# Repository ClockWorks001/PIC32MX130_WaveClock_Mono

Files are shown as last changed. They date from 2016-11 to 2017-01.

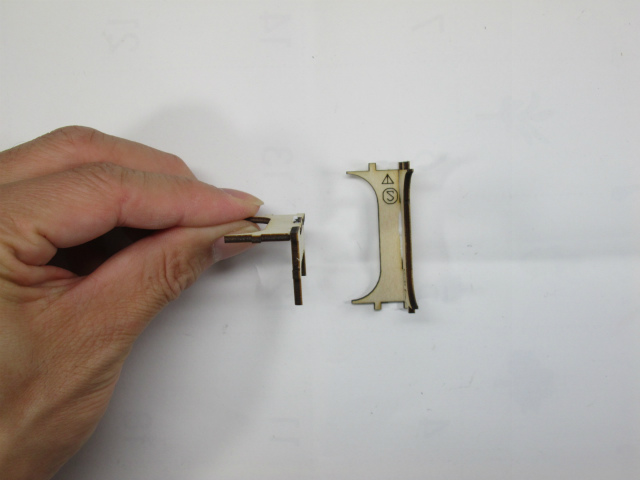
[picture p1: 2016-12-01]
組み立て参考情報【ケース】/IMG_1208.JPG

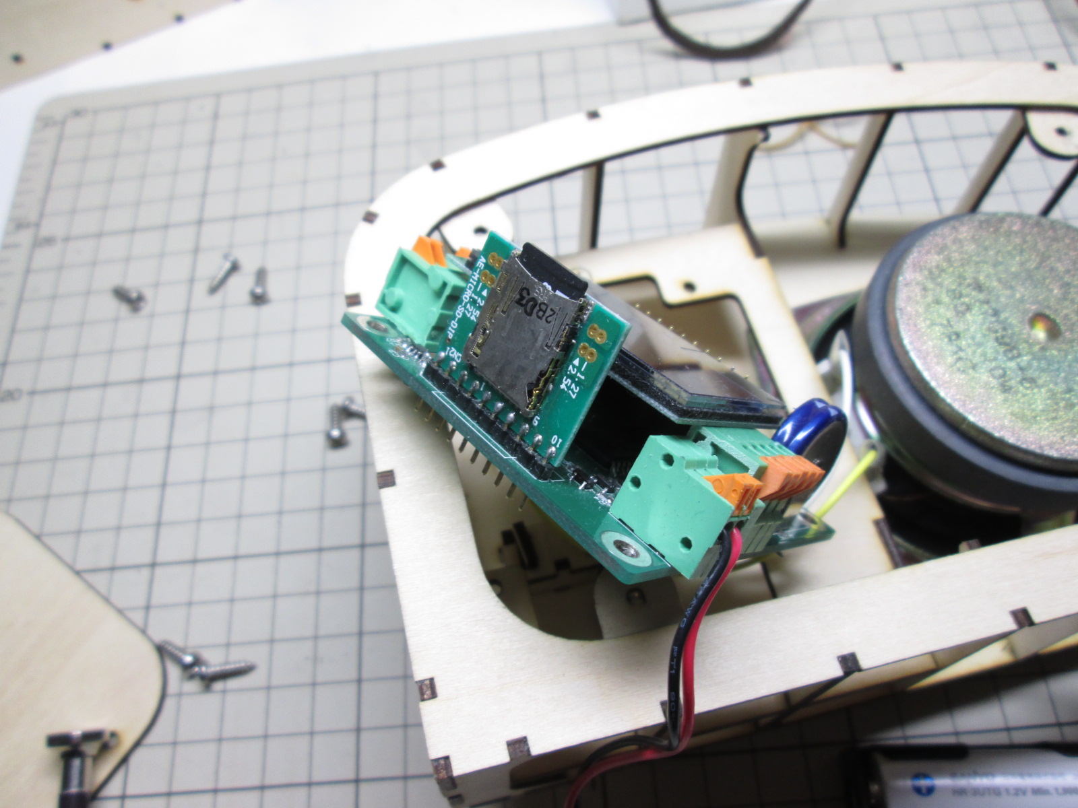
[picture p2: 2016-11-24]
組み立て参考情報/SDカードコネクタの取り付け位置①.JPG

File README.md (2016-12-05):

# PIC32MX130F Speaking Clock Project.
---
This is a wave player  project with PIC32MX130 micro controller.
It can speak a "time" by using wave files which are stored in a SD card. 
And it also can play music wave files.

## Description

References.
  <http://microchip.wikidot.com/>

## Prerequisites

I created this project using the free versions of the following tools:
 * [Microchip MPLAB X][2] (v3.35)
 * [Microchip XC32 Compiler][3] (v1.3)
 * [EAGLE][6] (v4.0.1)

You will need to download and install these tools appropriately before you
can open this project and build it.
I use the [Microchip MPLAB PICkit3 In-Circuit Debugger][5] to program the chip and debug it.  

Also, I use the [EAGLE][6] to draw the electric circuit schematic.

## Licence

[MIT](https://github.com/tcnksm/tool/blob/master/LICENCE)

## Author

Hiroshi Murakami  
<https://github.com/ClockWorks001>  

[1]: http://ww1.microchip.com/downloads/en/DeviceDoc/60001168F.pdf "PIC32MXxxx"
[2]: http://www.microchip.com/pagehandler/en-us/family/mplabx/ "MPLAB X"
[3]: http://www.microchip.com/pagehandler/en_us/devtools/mplabxc/ "MPLAB XC Compilers"
[4]: http://www.microchip.com/harmony "MPLAB Harmony Configurator"
[5]: http://www.microchip.com/Developmenttools/ProductDetails.aspx?PartNO=PG164130 "MPLAB PICkit3 In-Circuit Debugger"
[6]: https://cadsoft.io/ "EAGLE"

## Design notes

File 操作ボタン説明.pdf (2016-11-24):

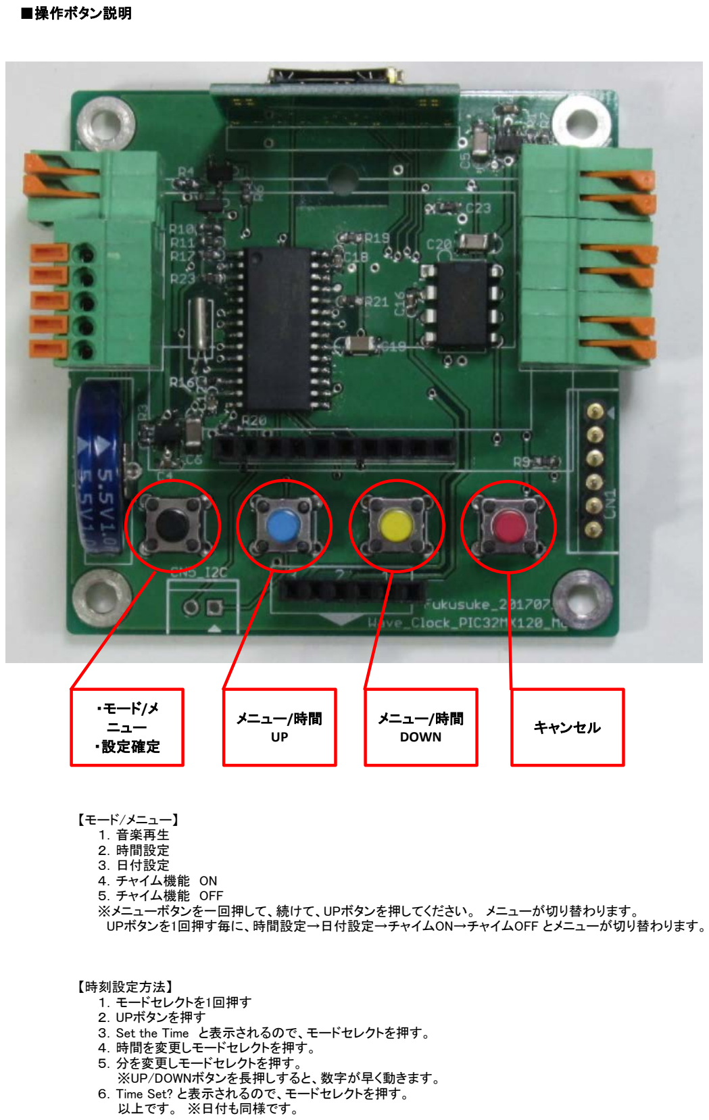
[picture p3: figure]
■操作ボタン説明; 【モード/メニュー】 １．音楽再生 ２．時間設定 ３．日付設定 ４．チャイム機能 ON ５．チャイム機能 OFF ※メニューボタンを一回押して、続けて、UPボタンを押してください。 メニューが切り替わります。 UPボタンを1回押す毎に、時間設定→日付設定→チャイムON→チャイムOFF とメニューが切り替わります。; 【時刻設定方法】 １．モードセレクトを1回押す ２．UPボタンを押す ３．Set the Time と表示されるので、モードセレクトを押す。 ４．時間を変更しモードセレクトを押す。 ５．分を変更しモードセレクトを押す。 ※UP/DOWNボタンを長押しすると、数字が早く動きます。 ６．Time Set? と表示されるので、モードセレクトを押す。 以上です。 ※日付も同様です。; ・モード/メ; ニュー ・設定確定; キャンセル メニュー/時間 UP; メニュー/時間 DOWN

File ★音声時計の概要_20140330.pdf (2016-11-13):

## 音声時計の概要_20140330.docx

音声時計の概要 2014.03.30

基本構成
1 CPU | PIC32MX130F064B
1.1 クロック | 40Mhz

## 1.2 ROM 64K 1.3 RAM 8K

2 周辺機能
2.1 microSD カード | 音声データ格納用
2.2 液晶表示器 | i2c_LCD SB1602B(ストロベリーリナックス)

## 2.3 オペアンプ（ローパスフィルタ） NJM8202 (JRC)

2.4 オーディオアンプ | HT82V739
2.5 入力スイッチ | 4 入力

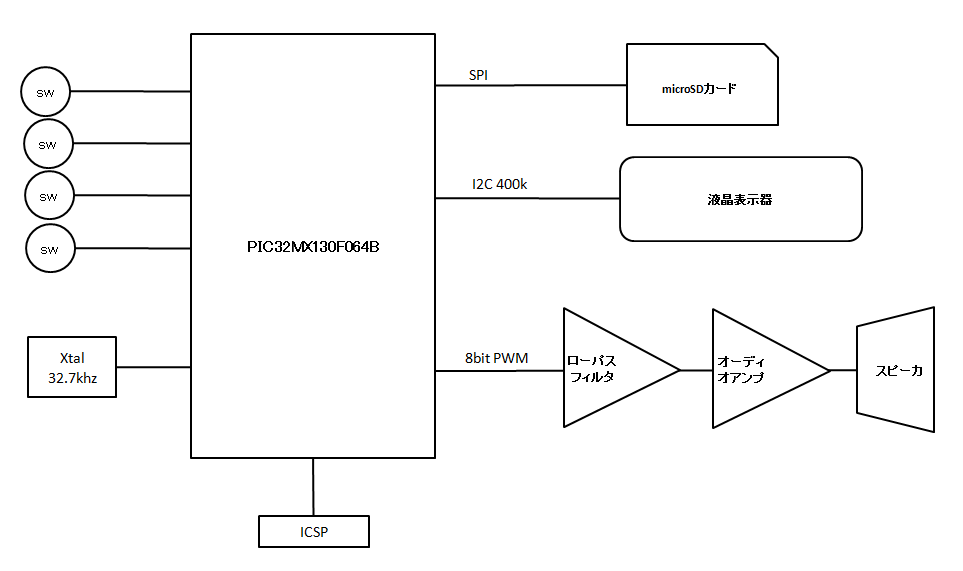
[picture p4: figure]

3 基本機能
3.1 ボタンを押すと、現在時刻を発話
3.2 時報機能。15 分ごとに現在時刻を発生。

## 3.3 PCM 音楽再生機能

3.4 音声データについては microSD カードに .wav(PCM)形式で格納して使用。 4 ソフトウェアの基本構成
4.1 ファイルシステムとして、ChaN 氏の PetitFAT を使用。
4.2 RTCC から読み出した時刻を元に Wave ファイルを再生する。
4.3 Wave ファイルの再生能力
4.3.1 入力ファイル | ：モノラル・ステレオ／ 8bit、16bit／ ～44.1Khz
4.3.2 出力 | ：モノラル／ 8bit PWM／ ～44.1Khz

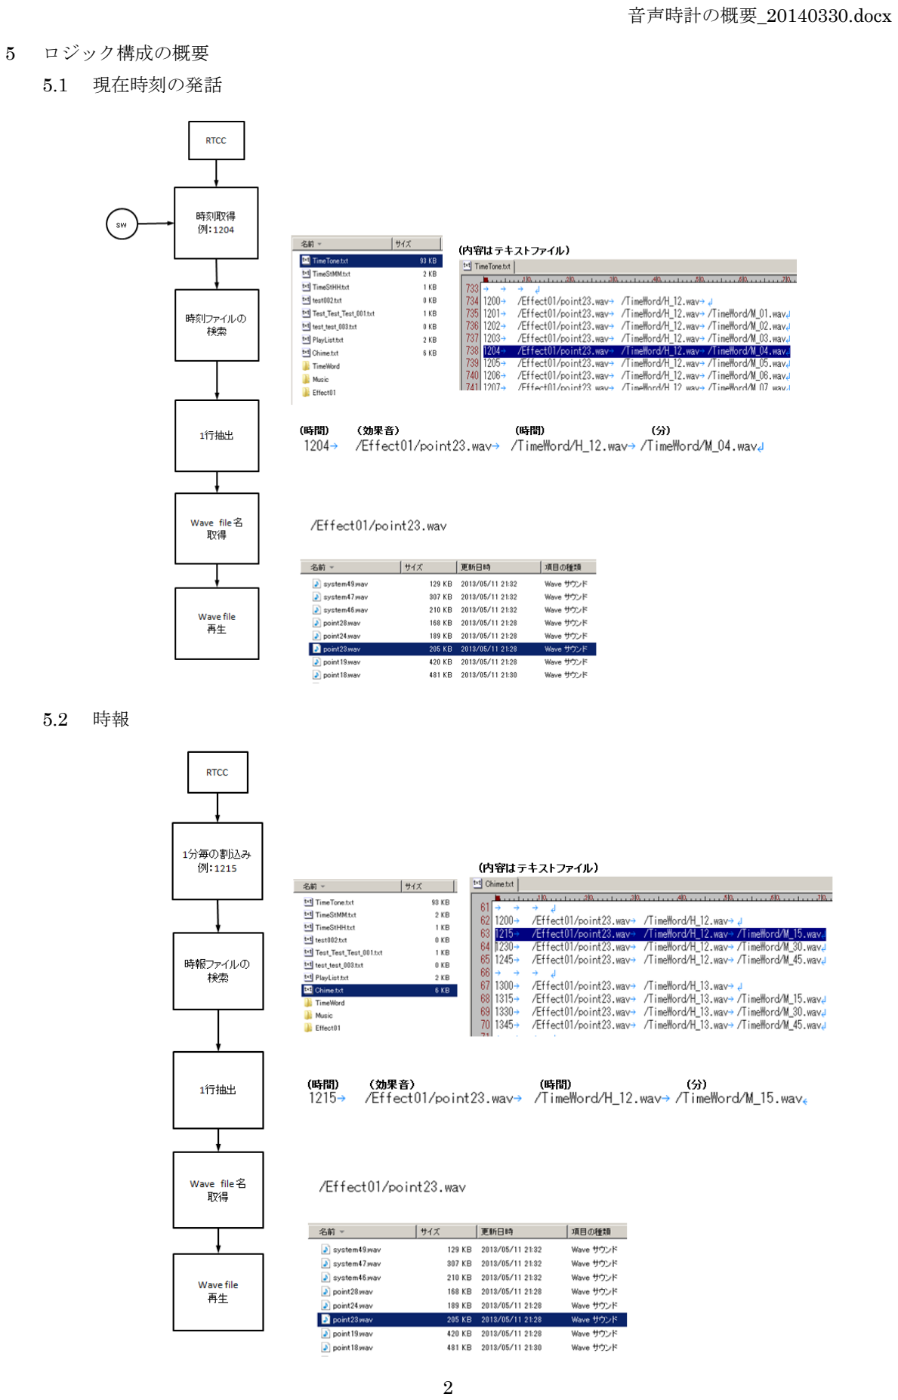
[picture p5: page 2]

5 ロジック構成の概要
5.1 現在時刻の発話

5.2 時報

6 使用ツールについて
6.1 ソフトウェア | ：MPLAB v1.90 ／ XC32 v1.21
6.2 回路図 | ：EGLE 6.4.0 light (P 板.COM に発注)
6.3 CAD | ：JW_CAD
6.4 3D_CAD | ：Autodesk123D Design (shapeways へ発注)
7 ケースの作成について (ケースについて、初めて 3D_CAD を使用して、3D 出力して作成しました) 7.1 JW_CAD を使用して、平面の設計図を作成する。
7.1.1 組み立てた基板をデジカメで写し、それを JW_CAD に貼り付けて設計の元とする。

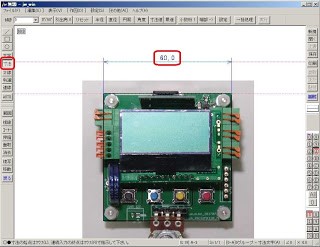
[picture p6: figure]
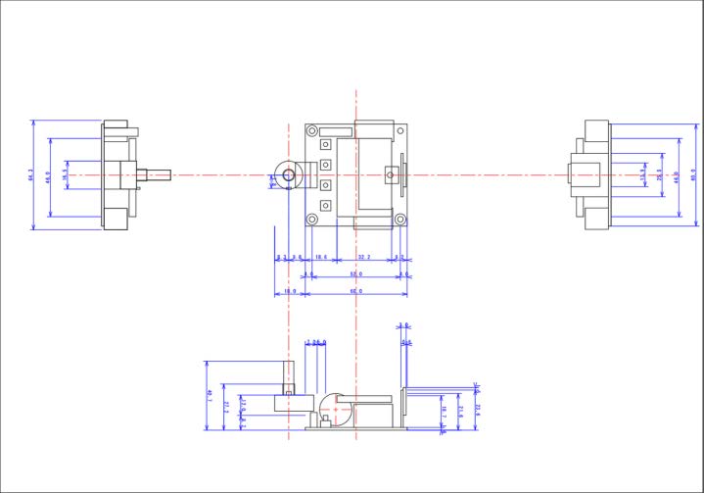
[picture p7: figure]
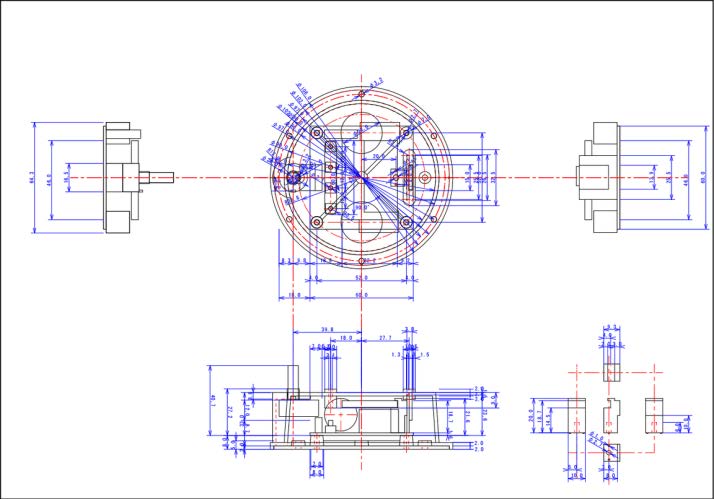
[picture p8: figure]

## 7.2 AutoCAD123 で 3D モデルを作成する。

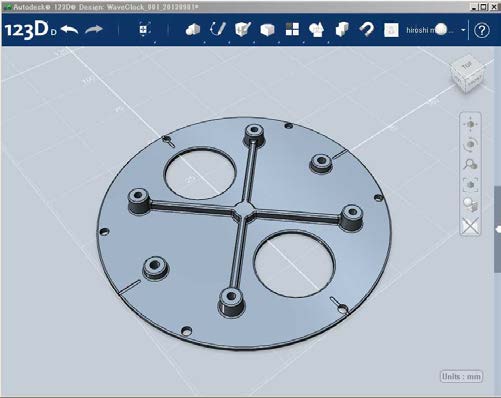
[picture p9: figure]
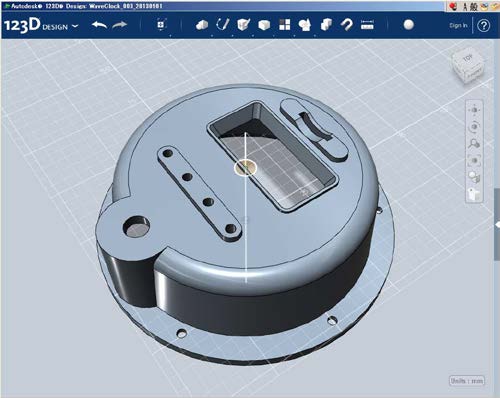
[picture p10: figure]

8 課題など
8.1 消費電力
8.1.1 オペアンプをレールツーレールのものを選択したが、無音時の待機電力が数ミリアンペアあ

り、削減が課題。
8.1.2 夜間に時報を発声してしまうので、センサを付けて明るさを検出する予定。
8.2 ユーザインターフェース部分の使いやすさの向上。
8.3 ファイルシステムを FatFs へ変更する。
8.4 ファイルの検索ロジックを、整理して再利用しやすくする。 8.5 Wave 再生ロジックについて、整理して再利用しやすくする。

※その他、下記ブログに音声時計の記事を記載しました。MPLAB のプロジェクトや設計図なども置いてあ

りますので、もしよろしければご参照ください。

## http://clockworks01.blogspot.jp/

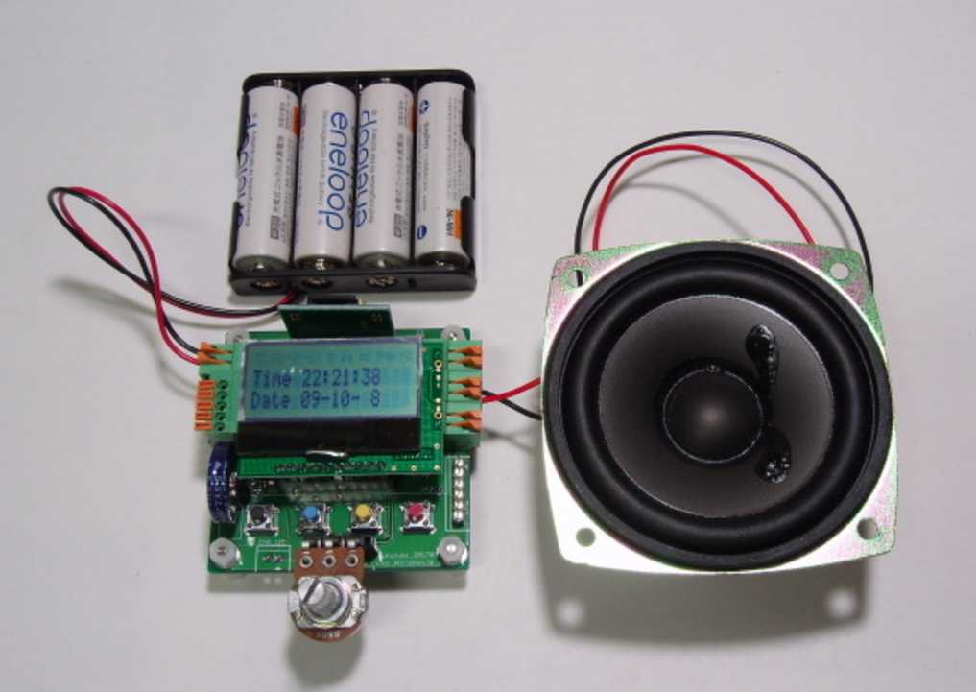
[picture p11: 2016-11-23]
組み立て参考情報/WS000727.JPG

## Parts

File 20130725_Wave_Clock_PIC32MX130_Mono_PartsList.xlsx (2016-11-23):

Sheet: 20130725_Wave_Clock_PIC32MX120_
Parts Listing
Part | Value | Package | 購入店
C7 | 1F | E5-19V-B | 秋月電子通商
C1 | 0.1uF | 1608 | 秋月電子通商
C2 | 0.1uF | 1608 | 秋月電子通商
C3 | 0.1uF | 1608 | 秋月電子通商
C4 | 0.1uF | 1608 | 秋月電子通商
C12 | 0.1uF | 1608 | 秋月電子通商
C17 | 0.1uF | 1608 | 秋月電子通商
C18 | 0.1uF | 1608 | 秋月電子通商
C21 | 0.1uF | 1608 | 秋月電子通商
C8 | 100pF | 1608 | 秋月電子通商
C11 | 100pF | 1608 | 秋月電子通商
C13 | 100pF | 1608 | 秋月電子通商
C14 | 100pF | 1608 | 秋月電子通商
C5 | 10uF | 3216 | 秋月電子通商
C6 | 10uF | 3216 | 秋月電子通商
C15 | 10uF | 3216 | 秋月電子通商
C19 | 10uF | 3216 | 秋月電子通商
C20 | 10uF | 3216 | 秋月電子通商
C22 | 10uF | 3216 | 秋月電子通商
C16 | 1uF | 1608 | 秋月電子通商
C23 | 1uF | 1608 | 秋月電子通商
C9 | 33pF | 1608 | 秋月電子通商
C10 | 33pF | 1608 | 秋月電子通商
BZ1 | R | TERMINAL_AH-2P | 秋月電子通商
CN2_POWER | CON_2P-B | TERMINAL_AH-2P | 秋月電子通商
CN6_SW | CON_2P-B | TERMINAL_AH-2P | 秋月電子通商
CN7_MOTOR | CON_2P-B | TERMINAL_AH-2P | 秋月電子通商
CN3_SWITCH | CON_5PVR | TERMINAL_AV-5P | 秋月電子通商
CN5_I2C | CON_2P-B | CON_DIP_2-B | 秋月電子通商
CN1 | CON_6P_ICSP-B | CON_DIP_6-B | 秋月電子通商
D1 | RB411D | SOT-23-3-2915-B | 秋月電子通商
IC1 | NJM2863F | SOT-23-5-2916-B | 秋月電子通商
IC2 | NJM2863F | SOT-23-5-2916-B | 秋月電子通商
IC3 | NJM8202R / LMV358QDGKR(12TI RHR) | MSOP08 | 秋月電子通商 / RSコンポーネンツ
IC4 | PIC32MX120F032B-I/SO | SO28W | digkey
IC5 | HT82V739 | DIP08-B | 秋月電子通商
IC6 | BD6211F | SOP8 | 秋月電子通商
LCD1 | LCD_I2CLCD_SB1602B | LCD_SB1602B | ストロベリーリナックス
R19 | 10 | 1608 | 秋月電子通商
R12 | 100 | 1608 | 秋月電子通商
R1 | 100K | 1608 | 秋月電子通商
R3 | 100K | 1608 | 秋月電子通商
R4 | 100K | 1608 | 秋月電子通商
R10 | 100K | 1608 | 秋月電子通商
R14 | 100K | 1608 | 秋月電子通商
R15 | 100K | 1608 | 秋月電子通商
R18 | 100K | 1608 | 秋月電子通商
R20 | 100K | 1608 | 秋月電子通商
R2 | 10K | 1608 | 秋月電子通商
R5 | 10K | 1608 | 秋月電子通商
R6 | 10K | 1608 | 秋月電子通商
R7 | 10K | 1608 | 秋月電子通商
R8 | 10K | 1608 | 秋月電子通商
R9 | 10K | 1608 | 秋月電子通商
R13 | 10K | 1608 | 秋月電子通商
R17 | 10K | 1608 | 秋月電子通商
R22 | 10K | 1608 | 秋月電子通商
R24 | 10K | 1608 | 秋月電子通商
R25 | 10K | 1608 | 秋月電子通商
R16 | 30K | 1608 | 秋月電子通商
R11 | 47K | 1608 | 秋月電子通商
R21 | 47K | 1608 | 秋月電子通商
R23 | 47K | 1608 | 秋月電子通商
SDC | DM3AT-SF-PEJ c | DM3AT-SF-DIP | 秋月電子通商
SW1 | SW_TACT1 | SW_TACT-B | 秋月電子通商
SW2 | SW_TACT1 | SW_TACT-B | 秋月電子通商
SW3 | SW_TACT1 | SW_TACT-B | 秋月電子通商
SW4 | SW_TACT1 | SW_TACT-B | 秋月電子通商
U1 | IRLML6402 | SC-59-2915 | 秋月電子通商
U2 | 2SC2712 | SOT-23-3-2915-B | 秋月電子通商
VR1 | ~~50K~~ 10K(A) | VOL_MIDDLE | 秋月電子通商
X1 | 32.768Khz | VT-200 | 秋月電子通商
 | 電池ボックス | 1
 | スピーカ | 1

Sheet: Sheet1
 | 0.1 uF | 100 pF | 10 uF
 | 1 uF | 33 pF
10 Ω |  | 100 Ω | 100 KΩ
10 KΩ |  | 30 KΩ | 47 KΩ

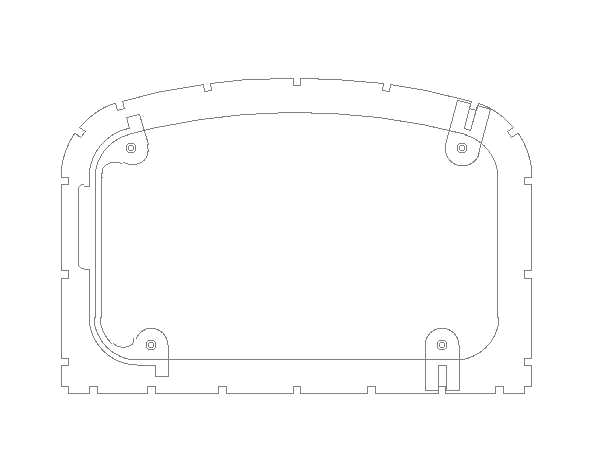
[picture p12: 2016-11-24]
組み立て参考情報【ケース】/IMG_1232_部品⑬は２種類.JPG

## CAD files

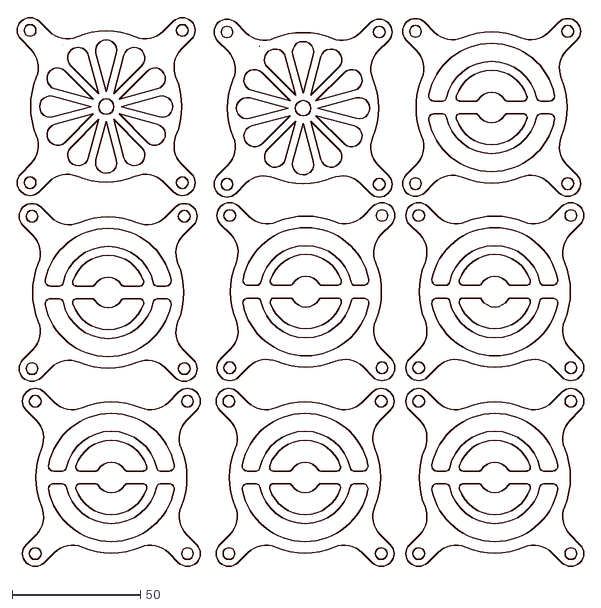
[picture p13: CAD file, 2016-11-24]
JWCAD/WaveClock_Mono_PIC32MX130_100.dxf
222.0 x 215.1

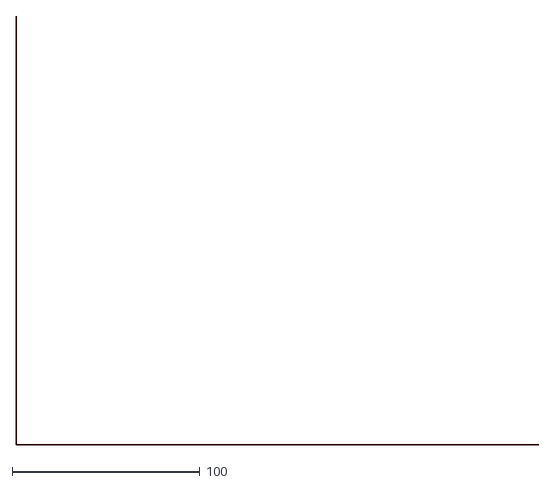
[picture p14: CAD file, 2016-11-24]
JWCAD/WaveClock_Mono_PIC32MX130_11_for_processing_00.dxf
278.0 x 228.0

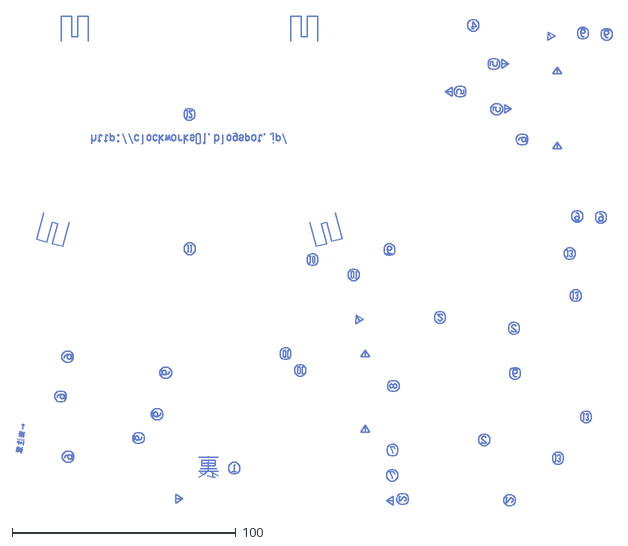
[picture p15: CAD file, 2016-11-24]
JWCAD/WaveClock_Mono_PIC32MX130_11_for_processing_01.dxf
266.3 x 218.6

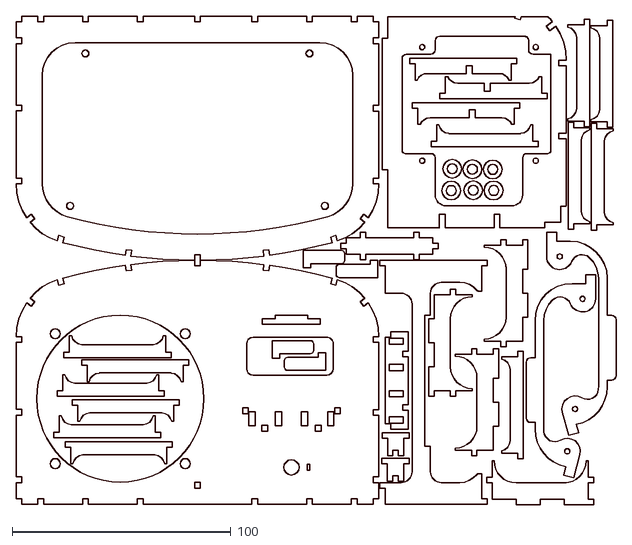
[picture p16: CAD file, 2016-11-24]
JWCAD/WaveClock_Mono_PIC32MX130_11_for_processing_02.dxf
274.4 x 223.4

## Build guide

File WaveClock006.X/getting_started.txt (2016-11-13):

This is a general template for the PIC32 family of microcontrollers.  It's
purpose is to provide a project shell for users to get started designing their
own applications.  Final qualification and testing of this project is left to
the user.

ADVANCED USER TIP

From the main menu, refer to the Task list by going to Window > Tasks (Ctrl+6).
As long as the task window is not configured to filter out any tasks,
the getting started TODO list embedded in this project will be displayed.

Make sure the 'Show tasks for the main project and for the open projects which
depend on it' option is selected on the left hand side of the Tasks window so
that tasks related to other projects are not active.

HOW TO ADD YOUR OWN CODE TO A TEMPLATE

STEP 1

First install the appropriate C compiler if you have not done so already.

See www.microchip.com/compilers

Next, build this project by clicking the Clean and Build Icon (the hammer and
broom symbol) in the MPLAB X IDE Toolbar.  If this project builds, then you are
ready to make changes for your own application.  If the project does not build,
you need to troubleshoot why the project does not build before moving on.

STEP 2

Embed your device's configuration bits into the code.  Instructions for this
are commented in configuration_bits.c

STEP 3

Unless interrupts are not used in your application, add the interrupt vectors
you intend to use to interrupts.c.  Code stubs are provided in interrupts.c.
Make sure that you check the device datasheet to confirm that the interrupt
you are using is present in the device selected, and check the device .h
file for the most up to date list of interrupt vector mnemonics.

STEP 4

Define system parameters such as the system operating frequency in system.h.

Add system level functions to system.h and system.c.  For example, if
you want a function to determine the reset source of the device to know if you
need to backup data, do an oscillator switch, enter a low power mode, etc...
these types of functions may be added to system.c and prototypes can go in
system.h.

STEP 5

Add user level functions to user.h and user.c.  User level functions are
functions that initialize I/O, initialize user peripherals like the ADC,
compute user algorithms, perform calculations on sampled user data, and so on.
User function prototypes and macros may be placed in user.h, and user
functions themselves may go in user.c

STEP 6

Add code to main.c on the line that says <INSERT USER APPLICATION CODE HERE>.
For example, here you would call functions in user.c or system.c, or possibly
setup your own state machine or primary code loop.

Global variables may be added to main.c as well.  As a general practice, macros
and prototypes may go in header files, but variable declarations should not
go in .h files.  Variable declarations should be placed in .c files.

STEP 7

Design the rest of your application.  Add new files to the application, and
test the finished product.

STEP 8

Document what the project does and include other project information in
project_information.txt.

KNOWN ISSUES

This message may appear after a successful build:

Configuration Bits: address 0x1FC02FF0: USERID = 22136 does not match any valid
value in the device database.  Setting it to the default value.

To avoid this message, the USERID may be embedded in the device as follows:

const int __attribute__((section(".config_BFC02FF0"))) configword_2ff0 = 0x12345678u;

(Adjust the address appropriately for the device in use if needed).

There will someday be a less painful way of embedding the USERID.  Until then,
this is how it can be done.

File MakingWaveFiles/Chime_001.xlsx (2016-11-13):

15分ごとの時間のお知らせ
 | 時間 | 分 | 格納先ディレクトリ |  | index
 | 00 | 00 | /TimeWord/ | na1_001.wav | 0000 | /Effect01/point23.wav | /TimeWord/H_00.wav
 | 00 | 15 | /TimeWord/ | point24.wav | 0015 | /Effect01/point23.wav | /TimeWord/H_00.wav | /TimeWord/M_15.wav
 | 00 | 30 | /TimeWord/ | point24.wav | 0030 | /Effect01/point23.wav | /TimeWord/H_00.wav | /TimeWord/M_30.wav
 | 00 | 45 | /TimeWord/ | point24.wav | 0045 | /Effect01/point23.wav | /TimeWord/H_00.wav | /TimeWord/M_45.wav
 | 01 | 00 | /TimeWord/ | na1_001.wav | 0100 | /Effect01/point23.wav | /TimeWord/H_01.wav
 | 01 | 15 | /TimeWord/ | point24.wav | 0115 | /Effect01/point23.wav | /TimeWord/H_01.wav | /TimeWord/M_15.wav
 | 01 | 30 | /TimeWord/ | point24.wav | 0130 | /Effect01/point23.wav | /TimeWord/H_01.wav | /TimeWord/M_30.wav
 | 01 | 45 | /TimeWord/ | point24.wav | 0145 | /Effect01/point23.wav | /TimeWord/H_01.wav | /TimeWord/M_45.wav
 | 02 | 00 | /TimeWord/ | na1_001.wav | 0200 | /Effect01/point23.wav | /TimeWord/H_02.wav
 | 02 | 15 | /TimeWord/ | point24.wav | 0215 | /Effect01/point23.wav | /TimeWord/H_02.wav | /TimeWord/M_15.wav
 | 02 | 30 | /TimeWord/ | point24.wav | 0230 | /Effect01/point23.wav | /TimeWord/H_02.wav | /TimeWord/M_30.wav
 | 02 | 45 | /TimeWord/ | point24.wav | 0245 | /Effect01/point23.wav | /TimeWord/H_02.wav | /TimeWord/M_45.wav
 | 03 | 00 | /TimeWord/ | na1_001.wav | 0300 | /Effect01/point23.wav | /TimeWord/H_03.wav
 | 03 | 15 | /TimeWord/ | point24.wav | 0315 | /Effect01/point23.wav | /TimeWord/H_03.wav | /TimeWord/M_15.wav
 | 03 | 30 | /TimeWord/ | point24.wav | 0330 | /Effect01/point23.wav | /TimeWord/H_03.wav | /TimeWord/M_30.wav
 | 03 | 45 | /TimeWord/ | point24.wav | 0345 | /Effect01/point23.wav | /TimeWord/H_03.wav | /TimeWord/M_45.wav
 | 04 | 00 | /TimeWord/ | na1_001.wav | 0400 | /Effect01/point23.wav | /TimeWord/H_04.wav
 | 04 | 15 | /TimeWord/ | point24.wav | 0415 | /Effect01/point23.wav | /TimeWord/H_04.wav | /TimeWord/M_15.wav
 | 04 | 30 | /TimeWord/ | point24.wav | 0430 | /Effect01/point23.wav | /TimeWord/H_04.wav | /TimeWord/M_30.wav
 | 04 | 45 | /TimeWord/ | point24.wav | 0445 | /Effect01/point23.wav | /TimeWord/H_04.wav | /TimeWord/M_45.wav
 | 05 | 00 | /TimeWord/ | na1_001.wav | 0500 | /Effect01/point23.wav | /TimeWord/H_05.wav
 | 05 | 15 | /TimeWord/ | point24.wav | 0515 | /Effect01/point23.wav | /TimeWord/H_05.wav | /TimeWord/M_15.wav
 | 05 | 30 | /TimeWord/ | point24.wav | 0530 | /Effect01/point23.wav | /TimeWord/H_05.wav | /TimeWord/M_30.wav
 | 05 | 45 | /TimeWord/ | point24.wav | 0545 | /Effect01/point23.wav | /TimeWord/H_05.wav | /TimeWord/M_45.wav
 | 06 | 00 | /TimeWord/ | na1_001.wav | 0600 | /Effect01/point23.wav | /TimeWord/H_06.wav
 | 06 | 15 | /TimeWord/ | point24.wav | 0615 | /Effect01/point23.wav | /TimeWord/H_06.wav | /TimeWord/M_15.wav
 | 06 | 30 | /TimeWord/ | point24.wav | 0630 | /Effect01/point23.wav | /TimeWord/H_06.wav | /TimeWord/M_30.wav
 | 06 | 45 | /TimeWord/ | point24.wav | 0645 | /Effect01/point23.wav | /TimeWord/H_06.wav | /TimeWord/M_45.wav
 | 07 | 00 | /TimeWord/ | na1_001.wav | 0700 | /Effect01/point23.wav | /TimeWord/H_07.wav
 | 07 | 15 | /TimeWord/ | point24.wav | 0715 | /Effect01/point23.wav | /TimeWord/H_07.wav | /TimeWord/M_15.wav
 | 07 | 30 | /TimeWord/ | point24.wav | 0730 | /Effect01/point23.wav | /TimeWord/H_07.wav | /TimeWord/M_30.wav
 | 07 | 45 | /TimeWord/ | point24.wav | 0745 | /Effect01/point23.wav | /TimeWord/H_07.wav | /TimeWord/M_45.wav
 | 08 | 00 | /TimeWord/ | na1_001.wav | 0800 | /Effect01/point23.wav | /TimeWord/H_08.wav
 | 08 | 15 | /TimeWord/ | point24.wav | 0815 | /Effect01/point23.wav | /TimeWord/H_08.wav | /TimeWord/M_15.wav
 | 08 | 30 | /TimeWord/ | point24.wav | 0830 | /Effect01/point23.wav | /TimeWord/H_08.wav | /TimeWord/M_30.wav
 | 08 | 45 | /TimeWord/ | point24.wav | 0845 | /Effect01/point23.wav | /TimeWord/H_08.wav | /TimeWord/M_45.wav
 | 09 | 00 | /TimeWord/ | na1_001.wav | 0900 | /Effect01/point23.wav | /TimeWord/H_09.wav
 | 09 | 15 | /TimeWord/ | point24.wav | 0915 | /Effect01/point23.wav | /TimeWord/H_09.wav | /TimeWord/M_15.wav
 | 09 | 30 | /TimeWord/ | point24.wav | 0930 | /Effect01/point23.wav | /TimeWord/H_09.wav | /TimeWord/M_30.wav
 | 09 | 45 | /TimeWord/ | point24.wav | 0945 | /Effect01/point23.wav | /TimeWord/H_09.wav | /TimeWord/M_45.wav
 | 10 | 00 | /TimeWord/ | na1_001.wav | 1000 | /Effect01/point23.wav | /TimeWord/H_10.wav
 | 10 | 15 | /TimeWord/ | point24.wav | 1015 | /Effect01/point23.wav | /TimeWord/H_10.wav | /TimeWord/M_15.wav
 | 10 | 30 | /TimeWord/ | point24.wav | 1030 | /Effect01/point23.wav | /TimeWord/H_10.wav | /TimeWord/M_30.wav
 | 10 | 45 | /TimeWord/ | point24.wav | 1045 | /Effect01/point23.wav | /TimeWord/H_10.wav | /TimeWord/M_45.wav
 | 11 | 00 | /TimeWord/ | na1_001.wav | 1100 | /Effect01/point23.wav | /TimeWord/H_11.wav
 | 11 | 15 | /TimeWord/ | point24.wav | 1115 | /Effect01/point23.wav | /TimeWord/H_11.wav | /TimeWord/M_15.wav
 | 11 | 30 | /TimeWord/ | point24.wav | 1130 | /Effect01/point23.wav | /TimeWord/H_11.wav | /TimeWord/M_30.wav
 | 11 | 45 | /TimeWord/ | point24.wav | 1145 | /Effect01/point23.wav | /TimeWord/H_11.wav | /TimeWord/M_45.wav
 | 12 | 00 | /TimeWord/ | na1_001.wav | 1200 | /Effect01/point23.wav | /TimeWord/H_12.wav
 | 12 | 15 | /TimeWord/ | point24.wav | 1215 | /Effect01/point23.wav | /TimeWord/H_12.wav | /TimeWord/M_15.wav
 | 12 | 30 | /TimeWord/ | point24.wav | 1230 | /Effect01/point23.wav | /TimeWord/H_12.wav | /TimeWord/M_30.wav
 | 12 | 45 | /TimeWord/ | point24.wav | 1245 | /Effect01/point23.wav | /TimeWord/H_12.wav | /TimeWord/M_45.wav
 | 13 | 00 | /TimeWord/ | na1_001.wav | 1300 | /Effect01/point23.wav | /TimeWord/H_13.wav
 | 13 | 15 | /TimeWord/ | point24.wav | 1315 | /Effect01/point23.wav | /TimeWord/H_13.wav | /TimeWord/M_15.wav
 | 13 | 30 | /TimeWord/ | point24.wav | 1330 | /Effect01/point23.wav | /TimeWord/H_13.wav | /TimeWord/M_30.wav
 | 13 | 45 | /TimeWord/ | point24.wav | 1345 | /Effect01/point23.wav | /TimeWord/H_13.wav | /TimeWord/M_45.wav
 | 14 | 00 | /TimeWord/ | na1_001.wav | 1400 | /Effect01/point23.wav | /TimeWord/H_14.wav
 | 14 | 15 | /TimeWord/ | point24.wav | 1415 | /Effect01/point23.wav | /TimeWord/H_14.wav | /TimeWord/M_15.wav
 | 14 | 30 | /TimeWord/ | point24.wav | 1430 | /Effect01/point23.wav | /TimeWord/H_14.wav | /TimeWord/M_30.wav
 | 14 | 45 | /TimeWord/ | point24.wav | 1445 | /Effect01/point23.wav | /TimeWord/H_14.wav | /TimeWord/M_45.wav
 | 15 | 00 | /TimeWord/ | na1_001.wav | 1500 | /Effect01/point23.wav | /TimeWord/H_15.wav
 | 15 | 15 | /TimeWord/ | point24.wav | 1515 | /Effect01/point23.wav | /TimeWord/H_15.wav | /TimeWord/M_15.wav
 | 15 | 30 | /TimeWord/ | point24.wav | 1530 | /Effect01/point23.wav | /TimeWord/H_15.wav | /TimeWord/M_30.wav
 | 15 | 45 | /TimeWord/ | point24.wav | 1545 | /Effect01/point23.wav | /TimeWord/H_15.wav | /TimeWord/M_45.wav
 | 16 | 00 | /TimeWord/ | na1_001.wav | 1600 | /Effect01/point23.wav | /TimeWord/H_16.wav
 | 16 | 15 | /TimeWord/ | point24.wav | 1615 | /Effect01/point23.wav | /TimeWord/H_16.wav | /TimeWord/M_15.wav
 | 16 | 30 | /TimeWord/ | point24.wav | 1630 | /Effect01/point23.wav | /TimeWord/H_16.wav | /TimeWord/M_30.wav
 | 16 | 45 | /TimeWord/ | point24.wav | 1645 | /Effect01/point23.wav | /TimeWord/H_16.wav | /TimeWord/M_45.wav
 | 17 | 00 | /TimeWord/ | na1_001.wav | 1700 | /Effect01/point23.wav | /TimeWord/H_17.wav
 | 17 | 15 | /TimeWord/ | point24.wav | 1715 | /Effect01/point23.wav | /TimeWord/H_17.wav | /TimeWord/M_15.wav
 | 17 | 30 | /TimeWord/ | point24.wav | 1730 | /Effect01/point23.wav | /TimeWord/H_17.wav | /TimeWord/M_30.wav
 | 17 | 45 | /TimeWord/ | point24.wav | 1745 | /Effect01/point23.wav | /TimeWord/H_17.wav | /TimeWord/M_45.wav
 | 18 | 00 | /TimeWord/ | na1_001.wav | 1800 | /Effect01/point23.wav | /TimeWord/H_18.wav
 | 18 | 15 | /TimeWord/ | point24.wav | 1815 | /Effect01/point23.wav | /TimeWord/H_18.wav | /TimeWord/M_15.wav
 | 18 | 30 | /TimeWord/ | point24.wav | 1830 | /Effect01/point23.wav | /TimeWord/H_18.wav | /TimeWord/M_30.wav
 | 18 | 45 | /TimeWord/ | point24.wav | 1845 | /Effect01/point23.wav | /TimeWord/H_18.wav | /TimeWord/M_45.wav
 | 19 | 00 | /TimeWord/ | na1_001.wav | 1900 | /Effect01/point23.wav | /TimeWord/H_19.wav
 | 19 | 15 | /TimeWord/ | point24.wav | 1915 | /Effect01/point23.wav | /TimeWord/H_19.wav | /TimeWord/M_15.wav
 | 19 | 30 | /TimeWord/ | point24.wav | 1930 | /Effect01/point23.wav | /TimeWord/H_19.wav | /TimeWord/M_30.wav
 | 19 | 45 | /TimeWord/ | point24.wav | 1945 | /Effect01/point23.wav | /TimeWord/H_19.wav | /TimeWord/M_45.wav
 | 20 | 00 | /TimeWord/ | na1_001.wav | 2000 | /Effect01/point23.wav | /TimeWord/H_20.wav
 | 20 | 15 | /TimeWord/ | point24.wav | 2015 | /Effect01/point23.wav | /TimeWord/H_20.wav | /TimeWord/M_15.wav
 | 20 | 30 | /TimeWord/ | point24.wav | 2030 | /Effect01/point23.wav | /TimeWord/H_20.wav | /TimeWord/M_30.wav
 | 20 | 45 | /TimeWord/ | point24.wav | 2045 | /Effect01/point23.wav | /TimeWord/H_20.wav | /TimeWord/M_45.wav
 | 21 | 00 | /TimeWord/ | na1_001.wav | 2100 | /Effect01/point23.wav | /TimeWord/H_21.wav
 | 21 | 15 | /TimeWord/ | point24.wav | 2115 | /Effect01/point23.wav | /TimeWord/H_21.wav | /TimeWord/M_15.wav
 | 21 | 30 | /TimeWord/ | point24.wav | 2130 | /Effect01/point23.wav | /TimeWord/H_21.wav | /TimeWord/M_30.wav
 | 21 | 45 | /TimeWord/ | point24.wav | 2145 | /Effect01/point23.wav | /TimeWord/H_21.wav | /TimeWord/M_45.wav
 | 22 | 00 | /TimeWord/ | na1_001.wav | 2200 | /Effect01/point23.wav | /TimeWord/H_22.wav
 | 22 | 15 | /TimeWord/ | point24.wav | 2215 | /Effect01/point23.wav | /TimeWord/H_22.wav | /TimeWord/M_15.wav
 | 22 | 30 | /TimeWord/ | point24.wav | 2230 | /Effect01/point23.wav | /TimeWord/H_22.wav | /TimeWord/M_30.wav
 | 22 | 45 | /TimeWord/ | point24.wav | 2245 | /Effect01/point23.wav | /TimeWord/H_22.wav | /TimeWord/M_45.wav
 | 23 | 00 | /TimeWord/ | na1_001.wav | 2300 | /Effect01/point23.wav | /TimeWord/H_23.wav
 | 23 | 15 | /TimeWord/ | point24.wav | 2315 | /Effect01/point23.wav | /TimeWord/H_23.wav | /TimeWord/M_15.wav
 | 23 | 30 | /TimeWord/ | point24.wav | 2330 | /Effect01/point23.wav | /TimeWord/H_23.wav | /TimeWord/M_30.wav
 | 23 | 45 | /TimeWord/ | point24.wav | 2345 | /Effect01/point23.wav | /TimeWord/H_23.wav | /TimeWord/M_45.wav

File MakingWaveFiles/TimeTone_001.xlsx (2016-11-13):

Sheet: TimeTone (1)
時間のお知らせ
 | 時間 | 分 | 格納先ディレクトリ | index
 | 00 | 00 | /TimeWord/ | 0000 | /Effect01/Apinpon1.wav | /TimeWord/H_00.wav
 | 00 | 01 | /TimeWord/ | 0001 | /Effect01/Apinpon1.wav | /TimeWord/H_00.wav | /TimeWord/M_01.wav
 | 00 | 02 | /TimeWord/ | 0002 | /Effect01/Apinpon1.wav | /TimeWord/H_00.wav | /TimeWord/M_02.wav
 | 00 | 03 | /TimeWord/ | 0003 | /Effect01/Apinpon1.wav | /TimeWord/H_00.wav | /TimeWord/M_03.wav
 | 00 | 04 | /TimeWord/ | 0004 | /Effect01/Apinpon1.wav | /TimeWord/H_00.wav | /TimeWord/M_04.wav
 | 00 | 05 | /TimeWord/ | 0005 | /Effect01/Apinpon1.wav | /TimeWord/H_00.wav | /TimeWord/M_05.wav
 | 00 | 06 | /TimeWord/ | 0006 | /Effect01/Apinpon1.wav | /TimeWord/H_00.wav | /TimeWord/M_06.wav
 | 00 | 07 | /TimeWord/ | 0007 | /Effect01/Apinpon1.wav | /TimeWord/H_00.wav | /TimeWord/M_07.wav
 | 00 | 08 | /TimeWord/ | 0008 | /Effect01/Apinpon1.wav | /TimeWord/H_00.wav | /TimeWord/M_08.wav
 | 00 | 09 | /TimeWord/ | 0009 | /Effect01/Apinpon1.wav | /TimeWord/H_00.wav | /TimeWord/M_09.wav
 | 00 | 10 | /TimeWord/ | 0010 | /Effect01/Apinpon1.wav | /TimeWord/H_00.wav | /TimeWord/M_10.wav
 | 00 | 11 | /TimeWord/ | 0011 | /Effect01/Apinpon1.wav | /TimeWord/H_00.wav | /TimeWord/M_11.wav
 | 00 | 12 | /TimeWord/ | 0012 | /Effect01/Apinpon1.wav | /TimeWord/H_00.wav | /TimeWord/M_12.wav
 | 00 | 13 | /TimeWord/ | 0013 | /Effect01/Apinpon1.wav | /TimeWord/H_00.wav | /TimeWord/M_13.wav
 | 00 | 14 | /TimeWord/ | 0014 | /Effect01/Apinpon1.wav | /TimeWord/H_00.wav | /TimeWord/M_14.wav
 | 00 | 15 | /TimeWord/ | 0015 | /Effect01/Apinpon1.wav | /TimeWord/H_00.wav | /TimeWord/M_15.wav
 | 00 | 16 | /TimeWord/ | 0016 | /Effect01/Apinpon1.wav | /TimeWord/H_00.wav | /TimeWord/M_16.wav
 | 00 | 17 | /TimeWord/ | 0017 | /Effect01/Apinpon1.wav | /TimeWord/H_00.wav | /TimeWord/M_17.wav
 | 00 | 18 | /TimeWord/ | 0018 | /Effect01/Apinpon1.wav | /TimeWord/H_00.wav | /TimeWord/M_18.wav
 | 00 | 19 | /TimeWord/ | 0019 | /Effect01/Apinpon1.wav | /TimeWord/H_00.wav | /TimeWord/M_19.wav
 | 00 | 20 | /TimeWord/ | 0020 | /Effect01/Apinpon1.wav | /TimeWord/H_00.wav | /TimeWord/M_20.wav
 | 00 | 21 | /TimeWord/ | 0021 | /Effect01/Apinpon1.wav | /TimeWord/H_00.wav | /TimeWord/M_21.wav
 | 00 | 22 | /TimeWord/ | 0022 | /Effect01/Apinpon1.wav | /TimeWord/H_00.wav | /TimeWord/M_22.wav
 | 00 | 23 | /TimeWord/ | 0023 | /Effect01/Apinpon1.wav | /TimeWord/H_00.wav | /TimeWord/M_23.wav
 | 00 | 24 | /TimeWord/ | 0024 | /Effect01/Apinpon1.wav | /TimeWord/H_00.wav | /TimeWord/M_24.wav
 | 00 | 25 | /TimeWord/ | 0025 | /Effect01/Apinpon1.wav | /TimeWord/H_00.wav | /TimeWord/M_25.wav
 | 00 | 26 | /TimeWord/ | 0026 | /Effect01/Apinpon1.wav | /TimeWord/H_00.wav | /TimeWord/M_26.wav
 | 00 | 27 | /TimeWord/ | 0027 | /Effect01/Apinpon1.wav | /TimeWord/H_00.wav | /TimeWord/M_27.wav
 | 00 | 28 | /TimeWord/ | 0028 | /Effect01/Apinpon1.wav | /TimeWord/H_00.wav | /TimeWord/M_28.wav
 | 00 | 29 | /TimeWord/ | 0029 | /Effect01/Apinpon1.wav | /TimeWord/H_00.wav | /TimeWord/M_29.wav
 | 00 | 30 | /TimeWord/ | 0030 | /Effect01/Apinpon1.wav | /TimeWord/H_00.wav | /TimeWord/M_30.wav
 | 00 | 31 | /TimeWord/ | 0031 | /Effect01/Apinpon1.wav | /TimeWord/H_00.wav | /TimeWord/M_31.wav
 | 00 | 32 | /TimeWord/ | 0032 | /Effect01/Apinpon1.wav | /TimeWord/H_00.wav | /TimeWord/M_32.wav
 | 00 | 33 | /TimeWord/ | 0033 | /Effect01/Apinpon1.wav | /TimeWord/H_00.wav | /TimeWord/M_33.wav
 | 00 | 34 | /TimeWord/ | 0034 | /Effect01/Apinpon1.wav | /TimeWord/H_00.wav | /TimeWord/M_34.wav
 | 00 | 35 | /TimeWord/ | 0035 | /Effect01/Apinpon1.wav | /TimeWord/H_00.wav | /TimeWord/M_35.wav
 | 00 | 36 | /TimeWord/ | 0036 | /Effect01/Apinpon1.wav | /TimeWord/H_00.wav | /TimeWord/M_36.wav
 | 00 | 37 | /TimeWord/ | 0037 | /Effect01/Apinpon1.wav | /TimeWord/H_00.wav | /TimeWord/M_37.wav
 | 00 | 38 | /TimeWord/ | 0038 | /Effect01/Apinpon1.wav | /TimeWord/H_00.wav | /TimeWord/M_38.wav
 | 00 | 39 | /TimeWord/ | 0039 | /Effect01/Apinpon1.wav | /TimeWord/H_00.wav | /TimeWord/M_39.wav
 | 00 | 40 | /TimeWord/ | 0040 | /Effect01/Apinpon1.wav | /TimeWord/H_00.wav | /TimeWord/M_40.wav
 | 00 | 41 | /TimeWord/ | 0041 | /Effect01/Apinpon1.wav | /TimeWord/H_00.wav | /TimeWord/M_41.wav
 | 00 | 42 | /TimeWord/ | 0042 | /Effect01/Apinpon1.wav | /TimeWord/H_00.wav | /TimeWord/M_42.wav
 | 00 | 43 | /TimeWord/ | 0043 | /Effect01/Apinpon1.wav | /TimeWord/H_00.wav | /TimeWord/M_43.wav
 | 00 | 44 | /TimeWord/ | 0044 | /Effect01/Apinpon1.wav | /TimeWord/H_00.wav | /TimeWord/M_44.wav
 | 00 | 45 | /TimeWord/ | 0045 | /Effect01/Apinpon1.wav | /TimeWord/H_00.wav | /TimeWord/M_45.wav
 | 00 | 46 | /TimeWord/ | 0046 | /Effect01/Apinpon1.wav | /TimeWord/H_00.wav | /TimeWord/M_46.wav
 | 00 | 47 | /TimeWord/ | 0047 | /Effect01/Apinpon1.wav | /TimeWord/H_00.wav | /TimeWord/M_47.wav
 | 00 | 48 | /TimeWord/ | 0048 | /Effect01/Apinpon1.wav | /TimeWord/H_00.wav | /TimeWord/M_48.wav
 | 00 | 49 | /TimeWord/ | 0049 | /Effect01/Apinpon1.wav | /TimeWord/H_00.wav | /TimeWord/M_49.wav
 | 00 | 50 | /TimeWord/ | 0050 | /Effect01/Apinpon1.wav | /TimeWord/H_00.wav | /TimeWord/M_50.wav
 | 00 | 51 | /TimeWord/ | 0051 | /Effect01/Apinpon1.wav | /TimeWord/H_00.wav | /TimeWord/M_51.wav
 | 00 | 52 | /TimeWord/ | 0052 | /Effect01/Apinpon1.wav | /TimeWord/H_00.wav | /TimeWord/M_52.wav
 | 00 | 53 | /TimeWord/ | 0053 | /Effect01/Apinpon1.wav | /TimeWord/H_00.wav | /TimeWord/M_53.wav
 | 00 | 54 | /TimeWord/ | 0054 | /Effect01/Apinpon1.wav | /TimeWord/H_00.wav | /TimeWord/M_54.wav
 | 00 | 55 | /TimeWord/ | 0055 | /Effect01/Apinpon1.wav | /TimeWord/H_00.wav | /TimeWord/M_55.wav
 | 00 | 56 | /TimeWord/ | 0056 | /Effect01/Apinpon1.wav | /TimeWord/H_00.wav | /TimeWord/M_56.wav
 | 00 | 57 | /TimeWord/ | 0057 | /Effect01/Apinpon1.wav | /TimeWord/H_00.wav | /TimeWord/M_57.wav
 | 00 | 58 | /TimeWord/ | 0058 | /Effect01/Apinpon1.wav | /TimeWord/H_00.wav | /TimeWord/M_58.wav
 | 00 | 59 | /TimeWord/ | 0059 | /Effect01/Apinpon1.wav | /TimeWord/H_00.wav | /TimeWord/M_59.wav
 | 01 | 00 | /TimeWord/ | 0100 | /Effect01/Apinpon1.wav | /TimeWord/H_01.wav
 | 01 | 01 | /TimeWord/ | 0101 | /Effect01/Apinpon1.wav | /TimeWord/H_01.wav | /TimeWord/M_01.wav
 | 01 | 02 | /TimeWord/ | 0102 | /Effect01/Apinpon1.wav | /TimeWord/H_01.wav | /TimeWord/M_02.wav
 | 01 | 03 | /TimeWord/ | 0103 | /Effect01/Apinpon1.wav | /TimeWord/H_01.wav | /TimeWord/M_03.wav
 | 01 | 04 | /TimeWord/ | 0104 | /Effect01/Apinpon1.wav | /TimeWord/H_01.wav | /TimeWord/M_04.wav
 | 01 | 05 | /TimeWord/ | 0105 | /Effect01/Apinpon1.wav | /TimeWord/H_01.wav | /TimeWord/M_05.wav
 | 01 | 06 | /TimeWord/ | 0106 | /Effect01/Apinpon1.wav | /TimeWord/H_01.wav | /TimeWord/M_06.wav
 | 01 | 07 | /TimeWord/ | 0107 | /Effect01/Apinpon1.wav | /TimeWord/H_01.wav | /TimeWord/M_07.wav
 | 01 | 08 | /TimeWord/ | 0108 | /Effect01/Apinpon1.wav | /TimeWord/H_01.wav | /TimeWord/M_08.wav
 | 01 | 09 | /TimeWord/ | 0109 | /Effect01/Apinpon1.wav | /TimeWord/H_01.wav | /TimeWord/M_09.wav
 | 01 | 10 | /TimeWord/ | 0110 | /Effect01/Apinpon1.wav | /TimeWord/H_01.wav | /TimeWord/M_10.wav
 | 01 | 11 | /TimeWord/ | 0111 | /Effect01/Apinpon1.wav | /TimeWord/H_01.wav | /TimeWord/M_11.wav
 | 01 | 12 | /TimeWord/ | 0112 | /Effect01/Apinpon1.wav | /TimeWord/H_01.wav | /TimeWord/M_12.wav
 | 01 | 13 | /TimeWord/ | 0113 | /Effect01/Apinpon1.wav | /TimeWord/H_01.wav | /TimeWord/M_13.wav
 | 01 | 14 | /TimeWord/ | 0114 | /Effect01/Apinpon1.wav | /TimeWord/H_01.wav | /TimeWord/M_14.wav
 | 01 | 15 | /TimeWord/ | 0115 | /Effect01/Apinpon1.wav | /TimeWord/H_01.wav | /TimeWord/M_15.wav
 | 01 | 16 | /TimeWord/ | 0116 | /Effect01/Apinpon1.wav | /TimeWord/H_01.wav | /TimeWord/M_16.wav
 | 01 | 17 | /TimeWord/ | 0117 | /Effect01/Apinpon1.wav | /TimeWord/H_01.wav | /TimeWord/M_17.wav
 | 01 | 18 | /TimeWord/ | 0118 | /Effect01/Apinpon1.wav | /TimeWord/H_01.wav | /TimeWord/M_18.wav
 | 01 | 19 | /TimeWord/ | 0119 | /Effect01/Apinpon1.wav | /TimeWord/H_01.wav | /TimeWord/M_19.wav
 | 01 | 20 | /TimeWord/ | 0120 | /Effect01/Apinpon1.wav | /TimeWord/H_01.wav | /TimeWord/M_20.wav
 | 01 | 21 | /TimeWord/ | 0121 | /Effect01/Apinpon1.wav | /TimeWord/H_01.wav | /TimeWord/M_21.wav
 | 01 | 22 | /TimeWord/ | 0122 | /Effect01/Apinpon1.wav | /TimeWord/H_01.wav | /TimeWord/M_22.wav
 | 01 | 23 | /TimeWord/ | 0123 | /Effect01/Apinpon1.wav | /TimeWord/H_01.wav | /TimeWord/M_23.wav
 | 01 | 24 | /TimeWord/ | 0124 | /Effect01/Apinpon1.wav | /TimeWord/H_01.wav | /TimeWord/M_24.wav
 | 01 | 25 | /TimeWord/ | 0125 | /Effect01/Apinpon1.wav | /TimeWord/H_01.wav | /TimeWord/M_25.wav
 | 01 | 26 | /TimeWord/ | 0126 | /Effect01/Apinpon1.wav | /TimeWord/H_01.wav | /TimeWord/M_26.wav
 | 01 | 27 | /TimeWord/ | 0127 | /Effect01/Apinpon1.wav | /TimeWord/H_01.wav | /TimeWord/M_27.wav
 | 01 | 28 | /TimeWord/ | 0128 | /Effect01/Apinpon1.wav | /TimeWord/H_01.wav | /TimeWord/M_28.wav
 | 01 | 29 | /TimeWord/ | 0129 | /Effect01/Apinpon1.wav | /TimeWord/H_01.wav | /TimeWord/M_29.wav
 | 01 | 30 | /TimeWord/ | 0130 | /Effect01/Apinpon1.wav | /TimeWord/H_01.wav | /TimeWord/M_30.wav
 | 01 | 31 | /TimeWord/ | 0131 | /Effect01/Apinpon1.wav | /TimeWord/H_01.wav | /TimeWord/M_31.wav
 | 01 | 32 | /TimeWord/ | 0132 | /Effect01/Apinpon1.wav | /TimeWord/H_01.wav | /TimeWord/M_32.wav
 | 01 | 33 | /TimeWord/ | 0133 | /Effect01/Apinpon1.wav | /TimeWord/H_01.wav | /TimeWord/M_33.wav
 | 01 | 34 | /TimeWord/ | 0134 | /Effect01/Apinpon1.wav | /TimeWord/H_01.wav | /TimeWord/M_34.wav
 | 01 | 35 | /TimeWord/ | 0135 | /Effect01/Apinpon1.wav | /TimeWord/H_01.wav | /TimeWord/M_35.wav
 | 01 | 36 | /TimeWord/ | 0136 | /Effect01/Apinpon1.wav | /TimeWord/H_01.wav | /TimeWord/M_36.wav
 | 01 | 37 | /TimeWord/ | 0137 | /Effect01/Apinpon1.wav | /TimeWord/H_01.wav | /TimeWord/M_37.wav
 | 01 | 38 | /TimeWord/ | 0138 | /Effect01/Apinpon1.wav | /TimeWord/H_01.wav | /TimeWord/M_38.wav
 | 01 | 39 | /TimeWord/ | 0139 | /Effect01/Apinpon1.wav | /TimeWord/H_01.wav | /TimeWord/M_39.wav
 | 01 | 40 | /TimeWord/ | 0140 | /Effect01/Apinpon1.wav | /TimeWord/H_01.wav | /TimeWord/M_40.wav
 | 01 | 41 | /TimeWord/ | 0141 | /Effect01/Apinpon1.wav | /TimeWord/H_01.wav | /TimeWord/M_41.wav
 | 01 | 42 | /TimeWord/ | 0142 | /Effect01/Apinpon1.wav | /TimeWord/H_01.wav | /TimeWord/M_42.wav
 | 01 | 43 | /TimeWord/ | 0143 | /Effect01/Apinpon1.wav | /TimeWord/H_01.wav | /TimeWord/M_43.wav
 | 01 | 44 | /TimeWord/ | 0144 | /Effect01/Apinpon1.wav | /TimeWord/H_01.wav | /TimeWord/M_44.wav
 | 01 | 45 | /TimeWord/ | 0145 | /Effect01/Apinpon1.wav | /TimeWord/H_01.wav | /TimeWord/M_45.wav
 | 01 | 46 | /TimeWord/ | 0146 | /Effect01/Apinpon1.wav | /TimeWord/H_01.wav | /TimeWord/M_46.wav
 | 01 | 47 | /TimeWord/ | 0147 | /Effect01/Apinpon1.wav | /TimeWord/H_01.wav | /TimeWord/M_47.wav
 | 01 | 48 | /TimeWord/ | 0148 | /Effect01/Apinpon1.wav | /TimeWord/H_01.wav | /TimeWord/M_48.wav
 | 01 | 49 | /TimeWord/ | 0149 | /Effect01/Apinpon1.wav | /TimeWord/H_01.wav | /TimeWord/M_49.wav
 | 01 | 50 | /TimeWord/ | 0150 | /Effect01/Apinpon1.wav | /TimeWord/H_01.wav | /TimeWord/M_50.wav
 | 01 | 51 | /TimeWord/ | 0151 | /Effect01/Apinpon1.wav | /TimeWord/H_01.wav | /TimeWord/M_51.wav
 | 01 | 52 | /TimeWord/ | 0152 | /Effect01/Apinpon1.wav | /TimeWord/H_01.wav | /TimeWord/M_52.wav
 | 01 | 53 | /TimeWord/ | 0153 | /Effect01/Apinpon1.wav | /TimeWord/H_01.wav | /TimeWord/M_53.wav
 | 01 | 54 | /TimeWord/ | 0154 | /Effect01/Apinpon1.wav | /TimeWord/H_01.wav | /TimeWord/M_54.wav
 | 01 | 55 | /TimeWord/ | 0155 | /Effect01/Apinpon1.wav | /TimeWord/H_01.wav | /TimeWord/M_55.wav
 | 01 | 56 | /TimeWord/ | 0156 | /Effect01/Apinpon1.wav | /TimeWord/H_01.wav | /TimeWord/M_56.wav
 | 01 | 57 | /TimeWord/ | 0157 | /Effect01/Apinpon1.wav | /TimeWord/H_01.wav | /TimeWord/M_57.wav
 | 01 | 58 | /TimeWord/ | 0158 | /Effect01/Apinpon1.wav | /TimeWord/H_01.wav | /TimeWord/M_58.wav
 | 01 | 59 | /TimeWord/ | 0159 | /Effect01/Apinpon1.wav | /TimeWord/H_01.wav | /TimeWord/M_59.wav
 | 02 | 00 | /TimeWord/ | 0200 | /Effect01/Apinpon1.wav | /TimeWord/H_02.wav
 | 02 | 01 | /TimeWord/ | 0201 | /Effect01/Apinpon1.wav | /TimeWord/H_02.wav | /TimeWord/M_01.wav
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

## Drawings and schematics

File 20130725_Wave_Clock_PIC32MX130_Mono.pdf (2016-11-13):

# X1 ¹_MCLR

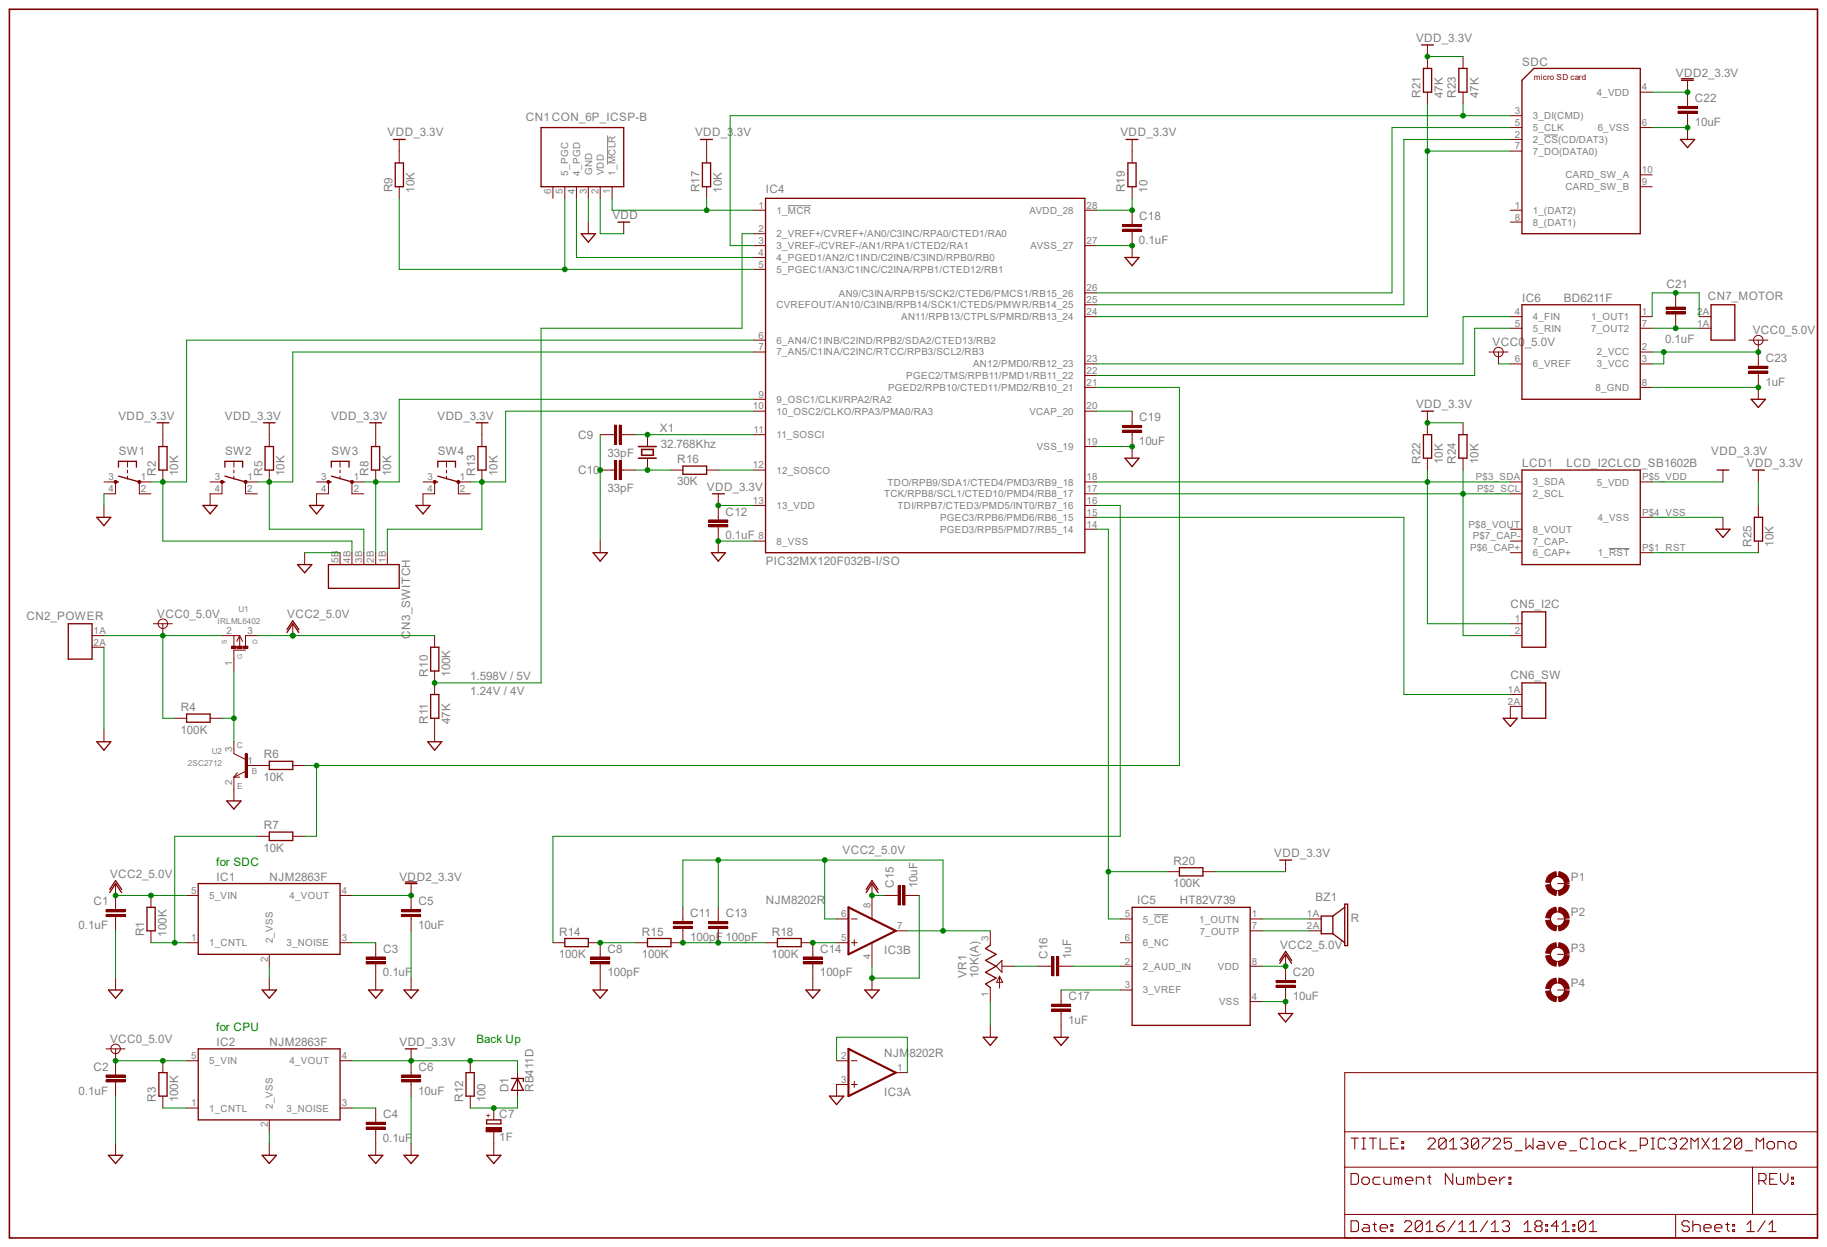
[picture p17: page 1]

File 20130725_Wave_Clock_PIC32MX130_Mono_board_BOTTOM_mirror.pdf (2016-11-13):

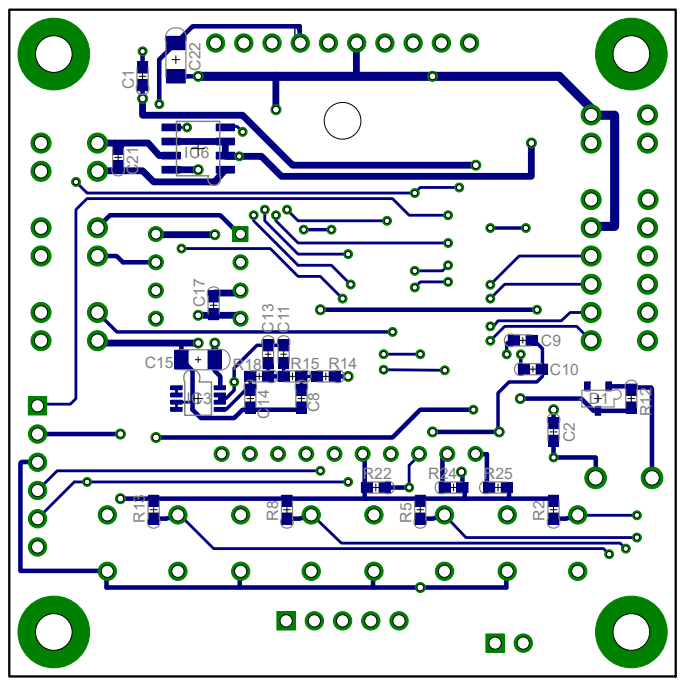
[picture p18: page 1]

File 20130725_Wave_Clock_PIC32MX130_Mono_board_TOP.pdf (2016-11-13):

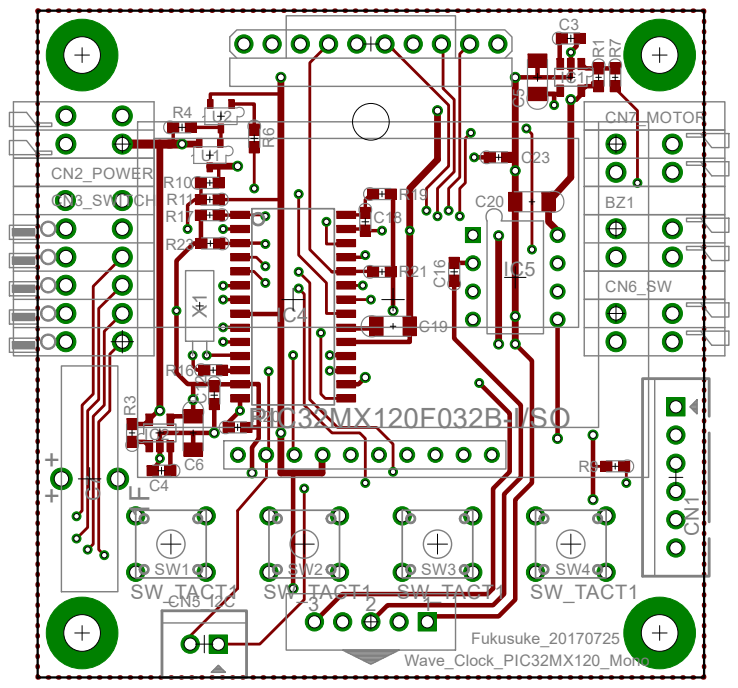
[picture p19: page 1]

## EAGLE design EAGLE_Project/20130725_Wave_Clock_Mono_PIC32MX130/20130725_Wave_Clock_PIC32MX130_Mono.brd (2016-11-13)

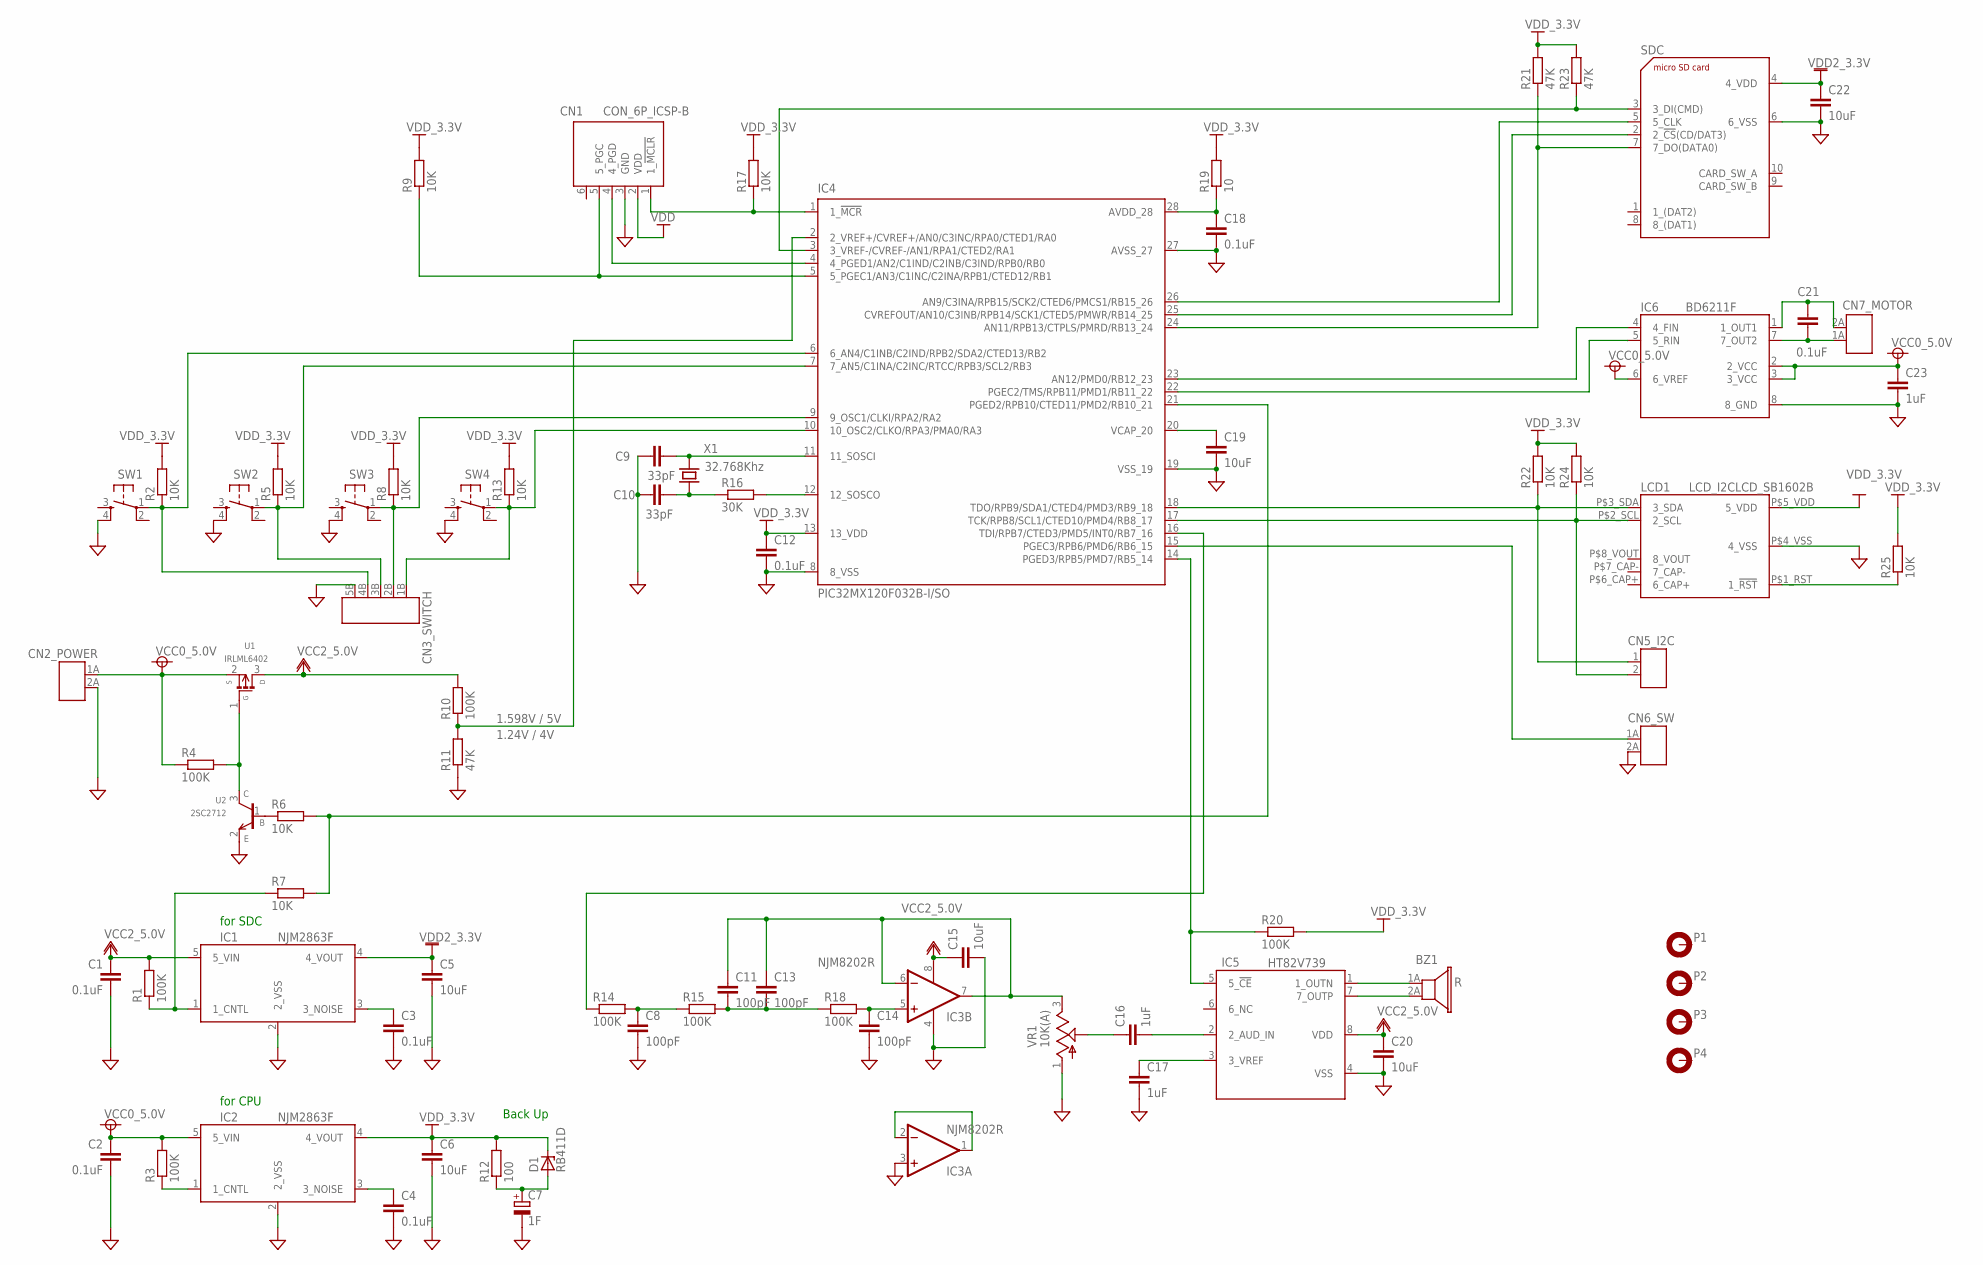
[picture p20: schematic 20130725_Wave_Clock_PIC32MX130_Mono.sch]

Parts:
BZ1: R; TERMINAL_AH-2P
C1, C2, C3, C4, C12, C18, C21: 0.1uF; 1608
C5, C6, C15, C19, C20, C22: 10uF; 3216
C7: 1F; E5-19V-B
C8, C11, C13, C14: 100pF; 1608
C9, C10: 33pF; 1608
C16, C17, C23: 1uF; 1608
CN1: CON_6P_ICSP-B; CON_DIP_6-B
CN2_POWER, CN6_SW, CN7_MOTOR: CON_2P-B; TERMINAL_AH-2P
CN3_SWITCH: CON_5PVR; TERMINAL_AV-5P
CN5_I2C: CON_2P-B; CON_DIP_2-B
D1: RB411D; SOT-23-3-2915-B
IC1, IC2: NJM2863F; SOT-23-5-2916-B
IC3: NJM8202R; MSOP08
IC4: PIC32MX120F032B-I/SO; SO28W
IC5: HT82V739; DIP08-B
IC6: BD6211F; SOP8
LCD1: LCD_I2CLCD_SB1602B; LCD_SB1602B
P1, P2, P3, P4: MOUNT-PAD3.3; PAD-3.3-B
R1, R3, R4, R10, R14, R15, R18, R20: 100K; 1608
R2, R5, R6, R7, R8, R9, R13, R17, R22, R24, R25: 10K; 1608
R11, R21, R23: 47K; 1608
R12: 100; 1608
R16: 30K; 1608
R19: 10; 1608
SDC: DM3AT-SF-PEJＤ; DM3AT-SF-DIP
SW1, SW2, SW3, SW4: SW_TACT1; SW_TACT-B
U1: IRLML6402; SC-59-2915
U2: 2SC2712; SOT-23-3-2915-B
VR1: 10K(A); VOL_MIDDLE
X1: 32.768Khz; VT-200

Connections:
GND: C1.2, C2.2, C3.2, C4.2, C5.2, C6.2, C7.-, C8.2, C9.2, C10.2, C12.2, C14.2, C15.2, C17.2, C18.2, C19.2, C20.2, C22.2, C23.2, CN1.3 (GND), CN2_POWER.2A (2), CN3_SWITCH.5B (5), CN6_SW.2A (2), IC1.2 (2_VSS), IC2.2 (2_VSS), IC3.3 (+IN), IC3.4 (V-), IC4.8 (8_VSS), IC4.19 (VSS_19), IC4.27 (AVSS_27), IC5.4 (VSS), IC6.8 (8_GND), LCD1.P$4_VSS (4_VSS), R11.1, SDC.6 (6_VSS), SW1.4 (S1), SW2.4 (S1), SW3.4 (S1), SW4.4 (S1), U2.2 (E), VR1.1 (A)
unnamed: CN1.1 (1_!MCLR), IC4.1 (1_!MCR), R17.1
unnamed: CN1.5 (5_PGC), IC4.5 (5_PGEC1/AN3/C1INC/C2INA/RPB1/CTED12/RB1), R9.1
unnamed: C18.1, IC4.28 (AVDD_28), R19.1
unnamed: C19.1, IC4.20 (VCAP_20)
unnamed: IC4.12 (12_SOSCO), R16.2
unnamed: C9.1, IC4.11 (11_SOSCI), X1.P$2 (2)
unnamed: CN1.4 (4_PGD), IC4.4 (4_PGED1/AN2/C1IND/C2INB/C3IND/RPB0/RB0)
unnamed: CN5_I2C.2, IC4.17 (TCK/RPB8/SCL1/CTED10/PMD4/RB8_17), LCD1.P$2_SCL (2_SCL), R24.1
unnamed: CN5_I2C.1, IC4.18 (TDO/RPB9/SDA1/CTED4/PMD3/RB9_18), LCD1.P$3_SDA (3_SDA), R22.1
unnamed: LCD1.P$1_RST (1_!RST), R25.1
unnamed: IC4.26 (AN9/C3INA/RPB15/SCK2/CTED6/PMCS1/RB15_26), SDC.5 (5_CLK)
unnamed: IC4.24 (AN11/RPB13/CTPLS/PMRD/RB13_24), R21.1, SDC.7 (7_DO(DATA0))
unnamed: IC4.25 (CVREFOUT/AN10/C3INB/RPB14/SCK1/CTED5/PM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), SDC.2 (2_!CS!(CD/DAT3))
unnamed: IC4.3 (3_VREF-/CVREF-/AN1/RPA1/CTED2/RA1), R23.1, SDC.3 (3_DI(CMD))
unnamed: CN3_SWITCH.2B (2), IC4.9 (9_OSC1/CLKI/RPA2/RA2), R8.1, SW3.1
unnamed: IC4.16 (TDI/RPB7/CTED3/PMD5/INT0/RB7_16), R14.1
unnamed: C14.1, IC3.5 (+IN), R18.2
unnamed: C8.1, R14.2, R15.1
unnamed: C11.2, C13.2, R15.2, R18.1
unnamed: IC3.1 (OUT), IC3.2 (-IN)
unnamed: CN6_SW.1A (1), IC4.15 (PGEC3/RPB6/PMD6/RB6_15)
unnamed: C17.1, IC5.3 (3_VREF)
unnamed: C16.2, IC5.2 (2_AUD_IN)
unnamed: BZ1.1A, IC5.1 (1_OUTN)
unnamed: BZ1.2A, IC5.7 (7_OUTP)
unnamed: C10.1, R16.1, X1.P$1 (1)
unnamed: R6.1, U2.1 (B)
unnamed: C16.1, VR1.2 (S)
unnamed: IC1.1 (1_CNTL), R1.1, R7.1
unnamed: C21.2, CN7_MOTOR.1A (1), IC6.7 (7_OUT2)
unnamed: C3.1, IC1.3 (3_NOISE)
unnamed: CN3_SWITCH.3B (3), IC4.7 (7_AN5/C1INA/C2INC/RTCC/RPB3/SCL2/RB3), R5.1, SW2.1
unnamed: C4.1, IC2.3 (3_NOISE)
unnamed: IC2.1 (1_CNTL), R3.1
unnamed: IC4.21 (PGED2/RPB10/CTED11/PMD2/RB10_21), R6.2, R7.2
unnamed: R4.2, U1.1 (G), U2.3 (C)
unnamed: CN3_SWITCH.4B (4), IC4.6 (6_AN4/C1INB/C2IND/RPB2/SDA2/CTED13/RB2), R2.1, SW1.1
unnamed: IC4.14 (PGED3/RPB5/PMD7/RB5_14), IC5.5 (5_!CE), R20.1
unnamed: CN3_SWITCH.1B (1), IC4.10 (10_OSC2/CLKO/RPA3/PMA0/RA3), R13.1, SW4.1
unnamed: C21.1, CN7_MOTOR.2A (2), IC6.1 (1_OUT1)
unnamed: C11.1, C13.1, IC3.6 (-IN), IC3.7 (OUT), VR1.3 (E)
unnamed: IC4.23 (AN12/PMD0/RB12_23), IC6.4 (4_FIN)
unnamed: IC4.22 (PGEC2/TMS/RPB11/PMD1/RB11_22), IC6.5 (5_RIN)
unnamed: IC4.2 (2_VREF+/CVREF+/AN0/C3INC/RPA0/CTED1/RA0), R10.1, R11.2
unnamed: C7.+, D1.1 (A), R12.1
VCC0: C2.1, C23.1, CN2_POWER.1A (1), IC2.5 (5_VIN), IC6.2 (2_VCC), IC6.3 (3_VCC), IC6.6 (6_VREF), R3.2, R4.1, U1.2 (S)
VCC2: C1.1, C15.1, C20.1, IC1.5 (5_VIN), IC3.8 (V+), IC5.8 (VDD), R1.2, R10.2, U1.3 (D)
VDD: C6.1, C12.1, CN1.2 (VDD), D1.3 (C), IC2.4 (4_VOUT), IC4.13 (13_VDD), LCD1.P$5_VDD (5_VDD), R2.2, R5.2, R8.2, R9.2, R12.2, R13.2, R17.2, R19.2, R20.2, R21.2, R22.2, R23.2, R24.2, R25.2
VDD2: C5.1, C22.1, IC1.4 (4_VOUT), SDC.4 (4_VDD)

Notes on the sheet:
for SDC
for CPU
Back Up
1.598V / 5V
1.24V / 4V

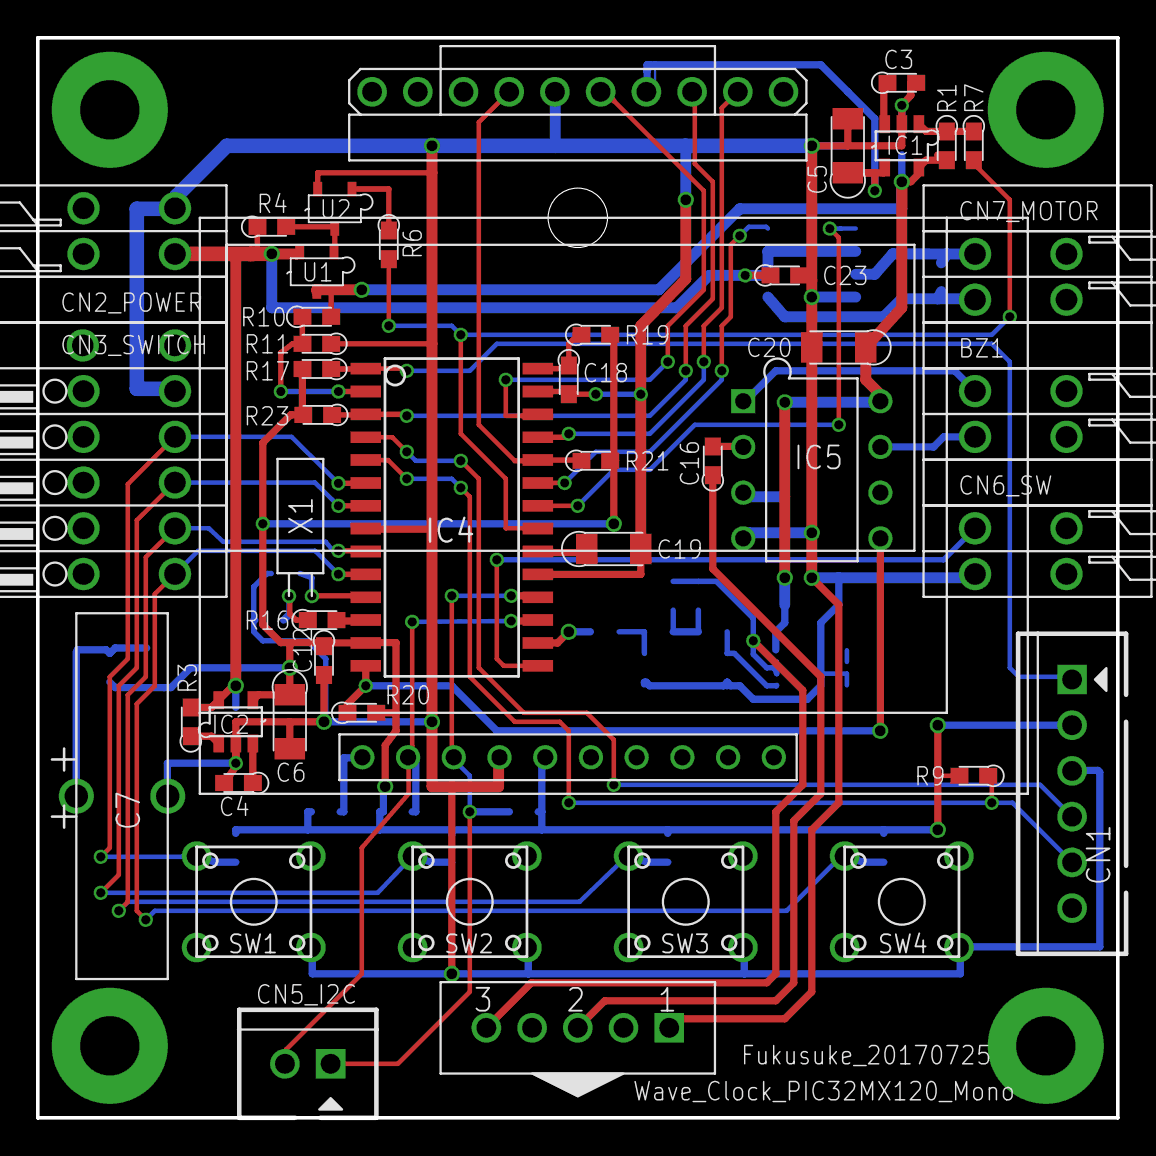
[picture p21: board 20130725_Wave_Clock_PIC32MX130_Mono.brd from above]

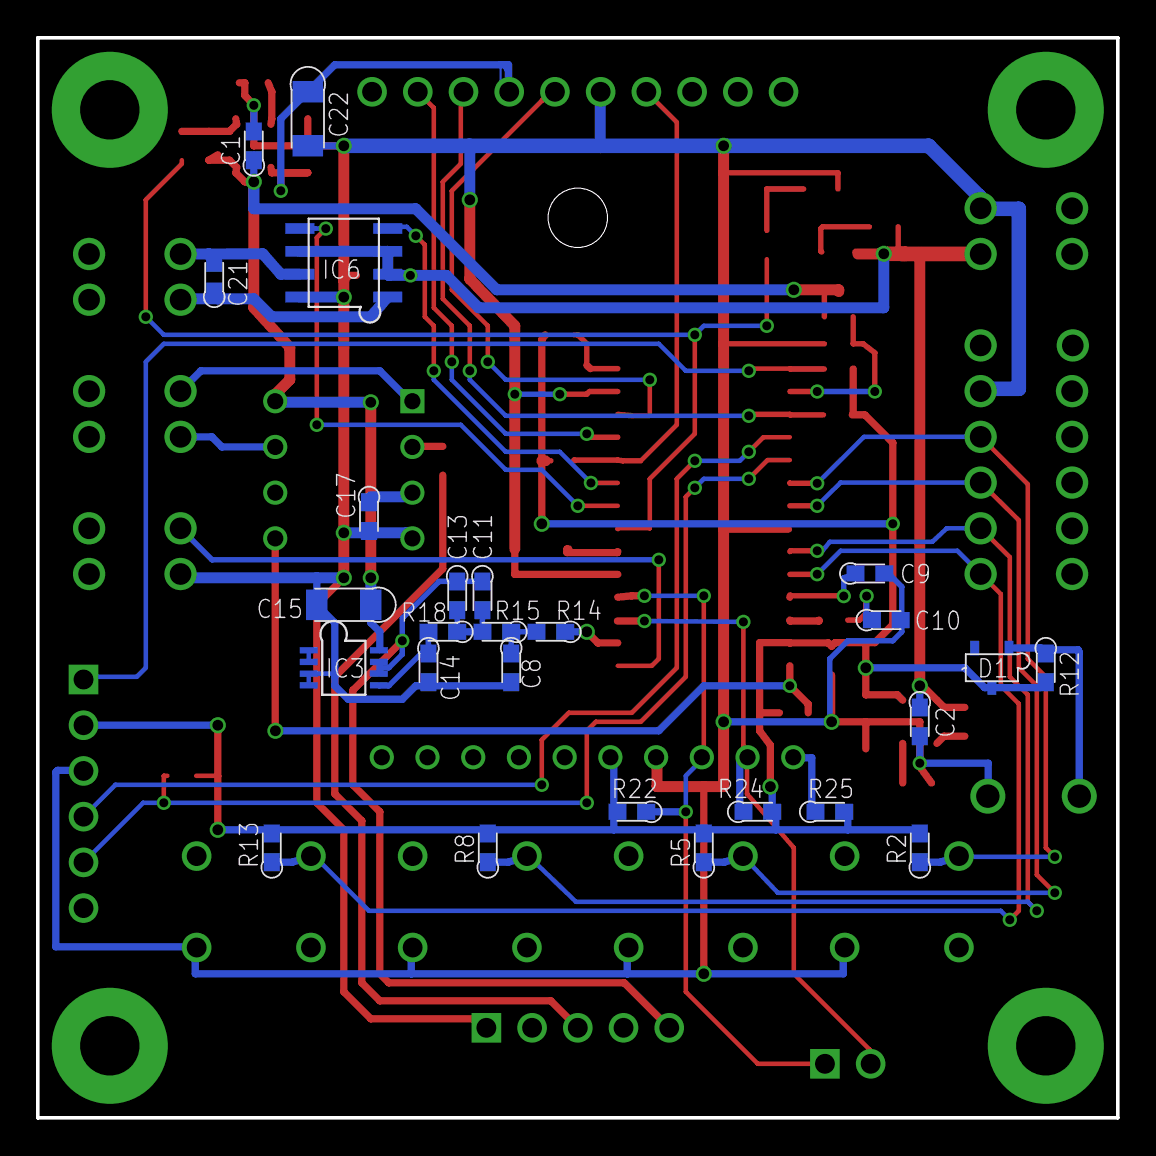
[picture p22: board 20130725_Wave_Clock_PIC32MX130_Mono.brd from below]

Board: 2 copper layers, 60.0 x 60.0 mm, 76 parts (26 on the bottom side), 50 nets.

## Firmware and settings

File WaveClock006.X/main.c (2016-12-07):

/******************************************************************************/
/*  Files to Include                                                          */
/******************************************************************************/
#ifdef __XC32
    #include <xc.h>          /* Defines special funciton registers, CP0 regs  */
#endif

#include <plib.h>           /* Include to use PIC32 peripheral libraries      */
#include <stdint.h>         /* For uint32_t definition                        */
#include <stdbool.h>        /* For true/false definition                      */

#include "system.h"         /* System funct/params, like osc/periph config    */
#include "user.h"           /* User funct/params, such as InitApp             */

/******************************************************************************/
/* Configuration Bits                                                         */
/******************************************************************************/

/* TODO Fill in your configuration bits from the config bits generator here.  */
#pragma config PMDL1WAY  = OFF		//Peripheral Module Disable Configuration:Allow multiple reconfigurations
#pragma config IOL1WAY   = OFF		//Peripheral Pin Select Configuration:Allow multiple reconfigurations
//#pragma config FUSBIDIO  = OFF		//USB USID Selection:Controlled by Port Function
//#pragma config FVBUSONIO = OFF		//USB VBUS ON Selection:Controlled by Port Function
#pragma config FPLLIDIV  = DIV_2
#pragma config FPLLMUL   = MUL_20
//#pragma config UPLLIDIV  = DIV_1		//USB PLL Input Divider:
//#pragma config UPLLEN	 = OFF			//USB PLL Enable:
#pragma config FPLLODIV  = DIV_2		//System PLL Output Clock Divider:
#pragma config FNOSC     = FRCPLL	//Fast RC Osc with PLL
#pragma config FSOSCEN   = ON		//Secondary Oscillator Enable:Enable (and SOSCEN has tobe ON)
#pragma config IESO      = ON		//Internal/External Switch Over:Enable
#pragma config POSCMOD   = OFF		//Primary Oscillator Configuration:Primary osc disabled (EC,XT,HS,OFF)
#pragma config OSCIOFNC  = OFF		//CLKO Output Signal Active on the OSCO Pin::disabled
#pragma config FPBDIV    = DIV_1	//Peripheral Clock Divisor:Pb_Clk is Sys_Clk/1 (DIV_1,DIV_2,DIV_4,DIV_8)
#pragma config FCKSM     = CSECMD	//Clock Switching and Monitor Selection:Clock Switch Disable, FSCM Disabled (CSECME,CSECMD,CSDCMD)
//#pragma config WDTPS     = PS1024		//Watchdog Timer Postscaler:1:1 (PS1,,,,PS1048576)
#pragma config WDTPS     = PS2048	//Watchdog Timer Postscaler:1:1 (PS1,,,,PS1048576)
#pragma config WINDIS    = OFF		//Watchdog Timer Window Enable:Watchdog Timer is in Non-Window Mode
#pragma config FWDTEN    = OFF		//Watchdog Timer Enable:WDT Disabled (SWDTEN Bit Controls)
#pragma config FWDTWINSZ = WISZ_25	//Watchdog Timer Window Size:Window Size is 50% (WINSZ_75,WINSZ_50,WINSZ_37,WISZ_25)
#pragma config DEBUG     = OFF		//Background Debugger Enable:Debugger is Disabled
#pragma config JTAGEN    = OFF		//JTAG Enable:JTAG Disabled
#pragma config ICESEL	 = ICS_PGx1	//ICE/ICD Comm Channel Select:Reserved (RESERVED,ICS_PGx3,ICS_PGx2,ICS_PGx1)
#pragma config PWP       = OFF		//Program Flash Write Protect:
#pragma config BWP       = OFF		//Boot Flash Write Protect bit:
#pragma config CP        = OFF		//Code Protect:

/******************************************************************************/
/* Global Variable Declaration                                                */
/******************************************************************************/

/* i.e. uint32_t <variable_name>; */


/******************************************************************************/
/* Main Program                                                               */
/******************************************************************************/

int32_t main(void)
{

    /*Refer to the C32 peripheral library documentation for more
    information on the SYTEMConfig function.
    
    This function sets the PB divider, the Flash Wait States, and the DRM
    /wait states to the optimum value.  It also enables the cacheability for
    the K0 segment.  It could has side effects of possibly alter the pre-fetch
    buffer and cache.  It sets the RAM wait states to 0.  Other than
    the SYS_FREQ, this takes these parameters.  The top 3 may be '|'ed
    together:
    
    SYS_CFG_WAIT_STATES (configures flash wait states from system clock)
    SYS_CFG_PB_BUS (configures the PB bus from the system clock)
    SYS_CFG_PCACHE (configures the pCache if used)
    SYS_CFG_ALL (configures the flash wait states, PB bus, and pCache)*/

    /* TODO Add user clock/system configuration code if appropriate.  */
    SYSTEMConfig(SYS_FREQ, SYS_CFG_ALL); 

    /*Configure Multivector Interrupt Mode.  Using Single Vector Mode
    is expensive from a timing perspective, so most applications
    should probably not use a Single Vector Mode*/
  	//マルチベクタ割り込み設定、割り込み許可
    INTConfigureSystem(INT_SYSTEM_CONFIG_MULT_VECTOR);
	IEC0 = IEC1 = IFS0 = IFS1 = 0;

    /* TODO <INSERT USER APPLICATION CODE HERE> */
    /* Initialize I/O and Peripherals for application */
    InitApp();

	INTEnableSystemMultiVectoredInt();

// *******************
//  2.Program Main
// *******************
    //while(1);
	user_main();

	return (EXIT_SUCCESS);


}

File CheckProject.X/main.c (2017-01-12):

/**
  Generated Main Source File

  Company:
    Microchip Technology Inc.

  File Name:
    main.c

  Summary:
    This is the main file generated using MPLAB(c) Code Configurator

  Description:
    This header file provides implementations for driver APIs for all modules selected in the GUI.
    Generation Information :
        Product Revision  :  MPLAB(c) Code Configurator - 4.0
        Device            :  PIC32MX130F064B
        Driver Version    :  2.00
    The generated drivers are tested against the following:
        Compiler          :  XC32 1.40
        MPLAB             :  MPLAB X 3.40
*/

/*
    (c) 2016 Microchip Technology Inc. and its subsidiaries. You may use this
    software and any derivatives exclusively with Microchip products.

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
    IN NO EVENT WILL MICROCHIP BE LIABLE FOR ANY INDIRECT, SPECIAL, PUNITIVE,
    INCIDENTAL OR CONSEQUENTIAL LOSS, DAMAGE, COST OR EXPENSE OF ANY KIND
    WHATSOEVER RELATED TO THE SOFTWARE, HOWEVER CAUSED, EVEN IF MICROCHIP HAS
    BEEN ADVISED OF THE POSSIBILITY OR THE DAMAGES ARE FORESEEABLE. TO THE
    FULLEST EXTENT ALLOWED BY LAW, MICROCHIP'S TOTAL LIABILITY ON ALL CLAIMS IN
    ANY WAY RELATED TO THIS SOFTWARE WILL NOT EXCEED THE AMOUNT OF FEES, IF ANY,
    THAT YOU HAVE PAID DIRECTLY TO MICROCHIP FOR THIS SOFTWARE.

    MICROCHIP PROVIDES THIS SOFTWARE CONDITIONALLY UPON YOUR ACCEPTANCE OF THESE
    TERMS.
*/

#include "mcc_generated_files/mcc.h"
#include "./integer.h"
#include "./vTMR1_lib.h"

#define LED1_Toggle()   IO_RB6_Toggle() 
#define AUDIO_EN()		LATBbits.LATB5 = 0	/* CS = L */
#define	AUDIO_DISEN()	LATBbits.LATB5 = 1	/* CS = H */
#define	AUDIO_CE_Toggle() IO_RB5_Toggle()
#define SD_POWER_EN()		LATBbits.LATB10 = 1	/* CS = H */
#define	SD_POWER_DISEN()	LATBbits.LATB10 = 0	/* CS = L */

/*
                         Main application
 */
int main(void)
{
    // initialize the device
    SYSTEM_Initialize();
    uiTMR001 = 0;
    
    AUDIO_EN();
    SD_POWER_EN();
    TMR1_Start();
    TMR2_Start();
//    TMR3_Start();
    OC1_Start();

    while (1)
    {
        // Add your application code
        
        if(FLAG_uiTMR001){
            uiTMR001 = 1000; //1000msec period
            LED1_Toggle(); 
        }
        
    }

    return -1;
}
/**
 End of File
*/

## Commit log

2016-11-23 add assemble explanation and photos
    [20130725_Wave_Clock_PIC32MX130_Mono_PartsList.xlsx, ★SDカード・フォルダ・WAVEファイルについて.xlsx, 操作ボタン説明.xlsx]
2016-11-24 added case assembly information.
    [操作ボタン説明.xlsx]
2016-11-24 added JWCAD data
    [WaveClock_Mono_PIC32MX130_100.dxf, WaveClock_Mono_PIC32MX130_11_for_processing_00.dxf, WaveClock_Mono_PIC32MX130_11_for_processing_01.dxf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]
2016-11-24 added case assembly note
2016-11-24 updated case assembly note
2016-12-01 updated the case assenble documents
